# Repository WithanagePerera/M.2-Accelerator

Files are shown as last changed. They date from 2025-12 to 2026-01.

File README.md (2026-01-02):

# Artix-7 M.2 Hardware Accelerator

A custom M.2 PCIe hardware accelerator based around an (Xilinx) Artix-7 XC7A100T-1FGG484C that I designed in Altium for my own embedded computer vision and DSP projects.

# Motivation

During the Fall 2025 semester, I was a Project Lead for the **Machine Intelligence Lab's** Software team, specifically Computer Vision. For our autonomous submersible (*sub9*), we had a huge stack of CV-algorithms that fed into each other, but I was frustrated with our real-time performance since we're heavily resource constrainted running on an embedded system.

Earlier that year, a friend (shoutout Zack Mendez, best Digital Design TA) showed me how he could write and deploy some video-filtering kernels onto an FPGA ([Zack's RTIPCV Project](https://github.com/zack-mendez/fpgators-rtipcv/tree/main)).

That got me thinking, our computer vision stack for the submersible has several basic pre-processing layers, so if I can move those to a hardware accelerator, I can free up more GPU/CPU resources for the more complex CNNs.

My hardware accelerator would need to be a small form factor with high bandwidth which was how I landed on M.2, which our computer (Jetson Nano) has on newer versions.

What really pushed me forward with this project was seeing an M.2 hardware accelerator built by Phil Salmony using an Artix-7 A35T, and it proved to me that something of this scale was possible.

A final motivation was having a chance to tinker with Altium more, especially with high speed designs. As an Electrical Engineer, I feel like PCB development is one of those quintessential skills that kind of defines us, and is especially useful as an Embedded/Hardware guy.

# Schematic Design (12/20/25 - 01/01/26)

Took a break from my [SystemVerilog I2C-IP project](https://github.com/WithanagePerera/I2C-Interface-IP) to work on this.

Spent this time for my component selection, then designing all of my circuits in Altium like the power distribution for all of my voltage rails, configuration of the FPGA banks, the MGTs for PCIe, DDR3L, QSPI and JTAG, etc.

I plan on taking a break from this to finish off my I2C project, but the next step is validation of my circuits and running some signal integrity checks to check my transmission line effects on the high speed signals, then finally PCB development.

<table align="center" border="0">
  <tr>
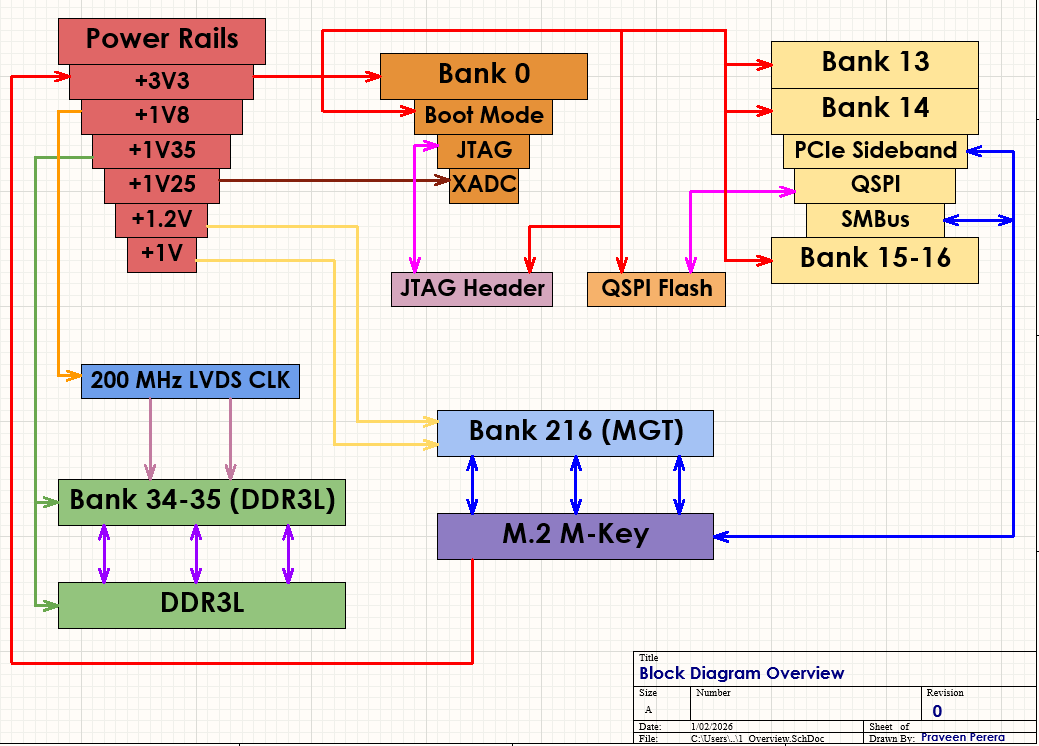
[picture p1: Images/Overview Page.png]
Block Diagram Overview
    <td></td>
  </tr>
  <tr>
    <td align="center" style="background:none;">Block Diagram Overview</td>
  </tr>
</table>

<br/>

<table align="center" border="0">
  <tr>
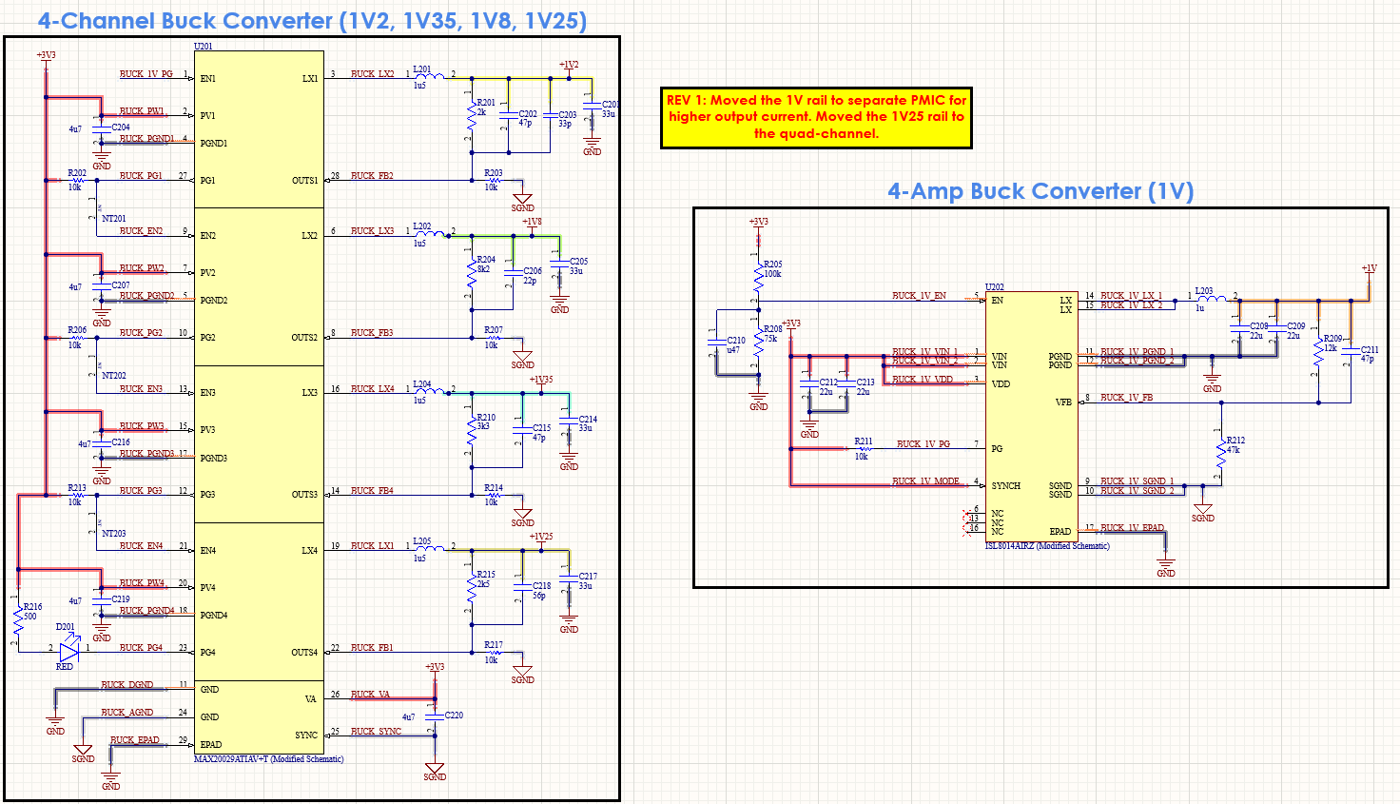
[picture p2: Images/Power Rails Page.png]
Power Rails
    <td width="50%"></td>
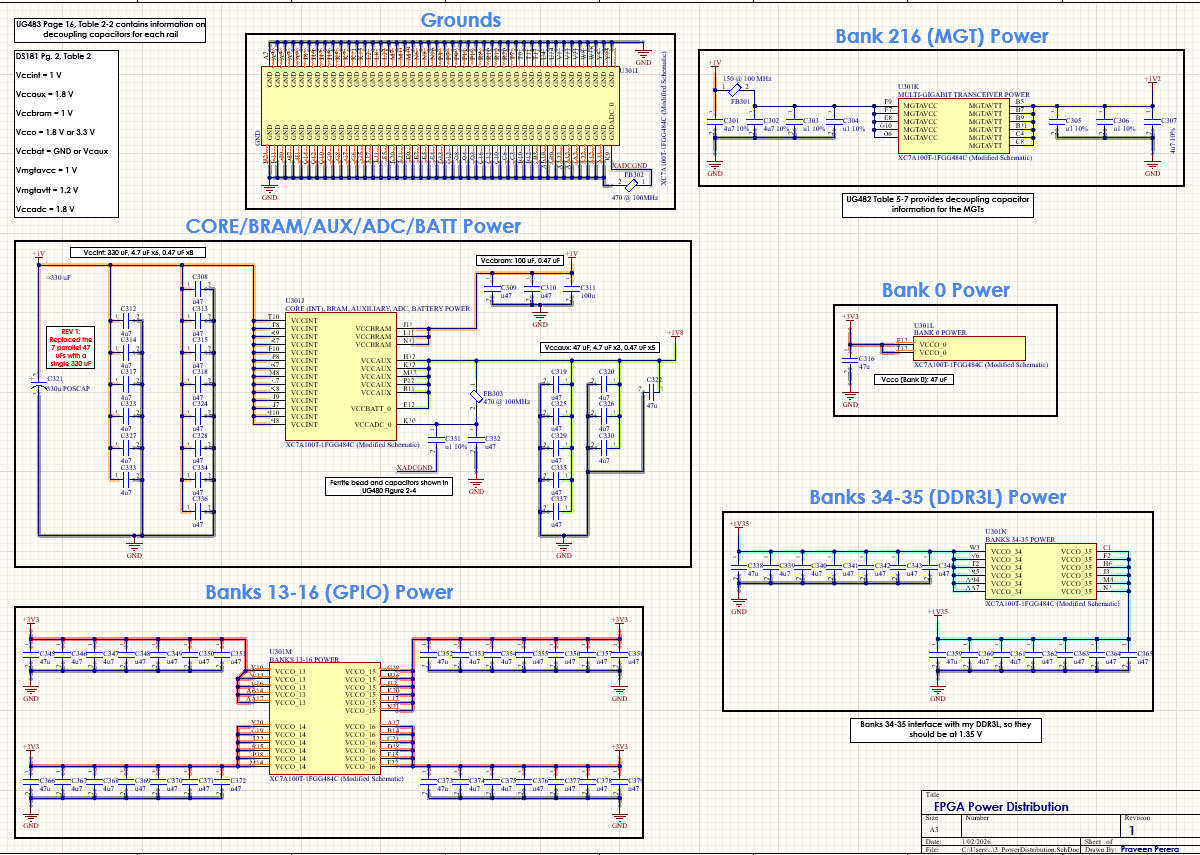
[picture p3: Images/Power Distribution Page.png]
Power Distribution
    <td width="50%"></td>
  </tr>
  <tr>
    <td align="center" style="background:none;">Power Distribution</td>
    <td align="center" style="background:none;">Power Rails</td>
  </tr>
</table>

<br/>

<table align="center" border="0">
  <tr>
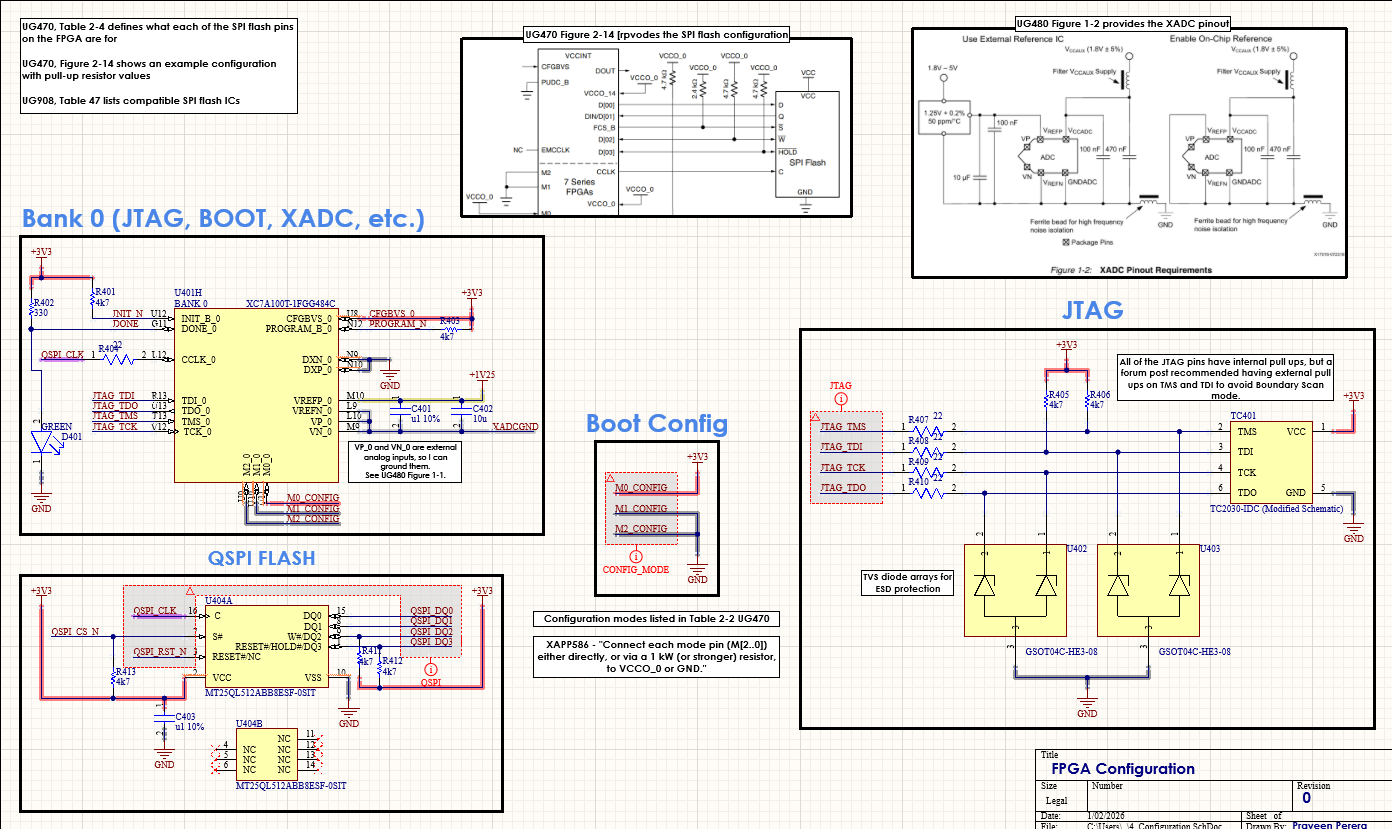
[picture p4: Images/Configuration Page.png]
FPGA Configuration
    <td width="50%"></td>
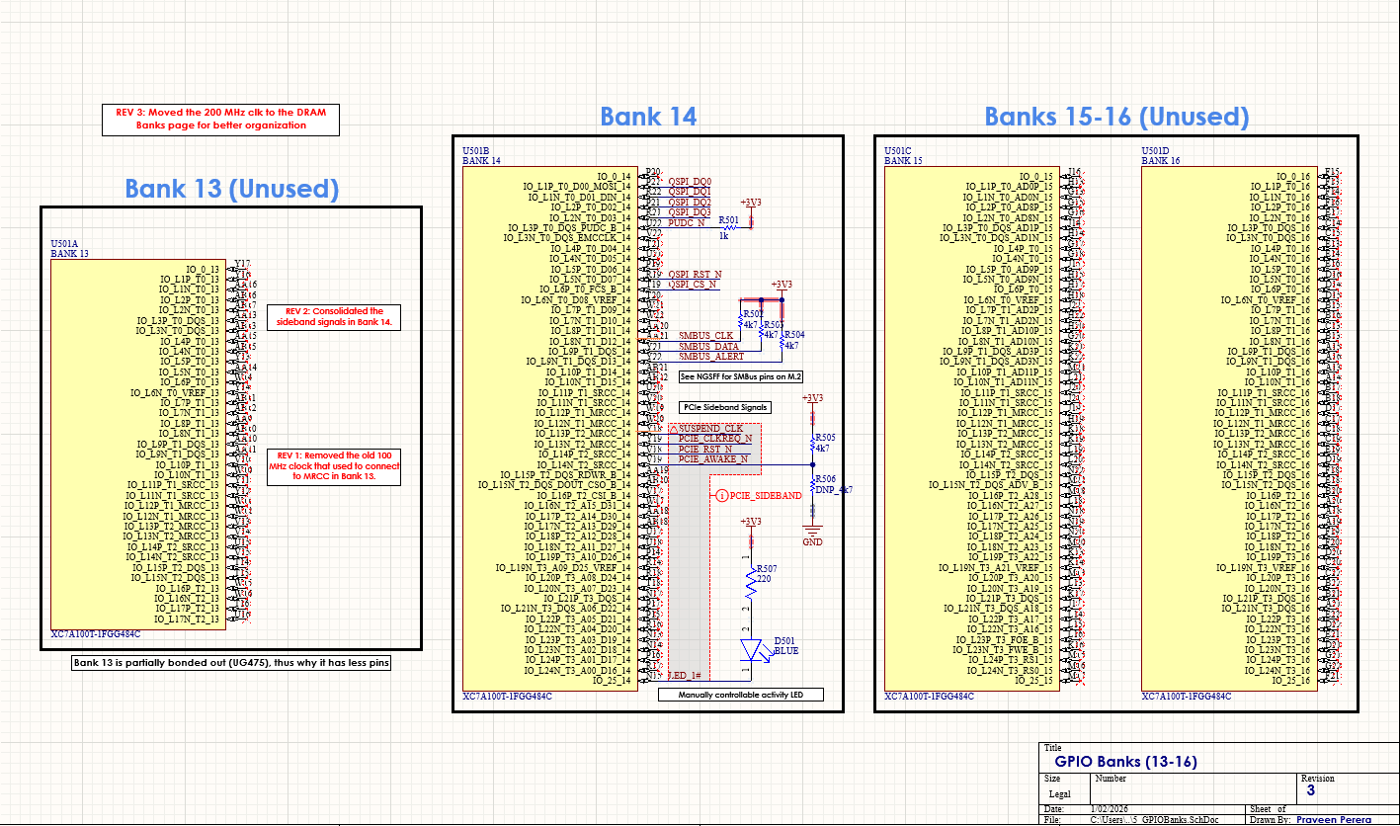
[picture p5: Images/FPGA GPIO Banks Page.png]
GPIO Banks
    <td width="50%"></td>
  </tr>
  <tr>
    <td align="center" style="background:none;">FPGA Configuration</td>
    <td align="center" style="background:none;">GPIO Banks</td>
  </tr>
</table>

<br/>

<table align="center" border="0">
  <tr>
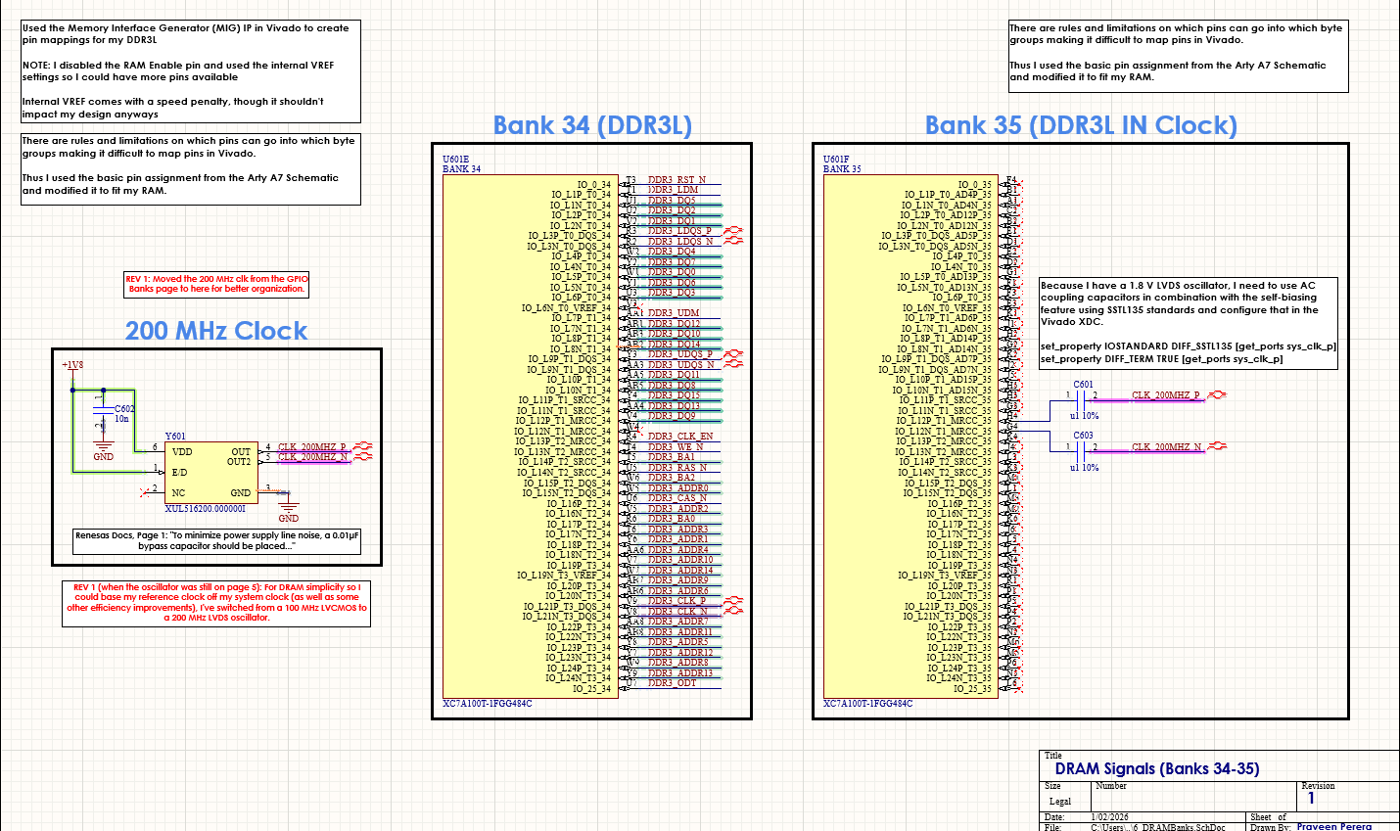
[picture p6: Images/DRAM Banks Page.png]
DRAM Banks
    <td width="50%"></td>
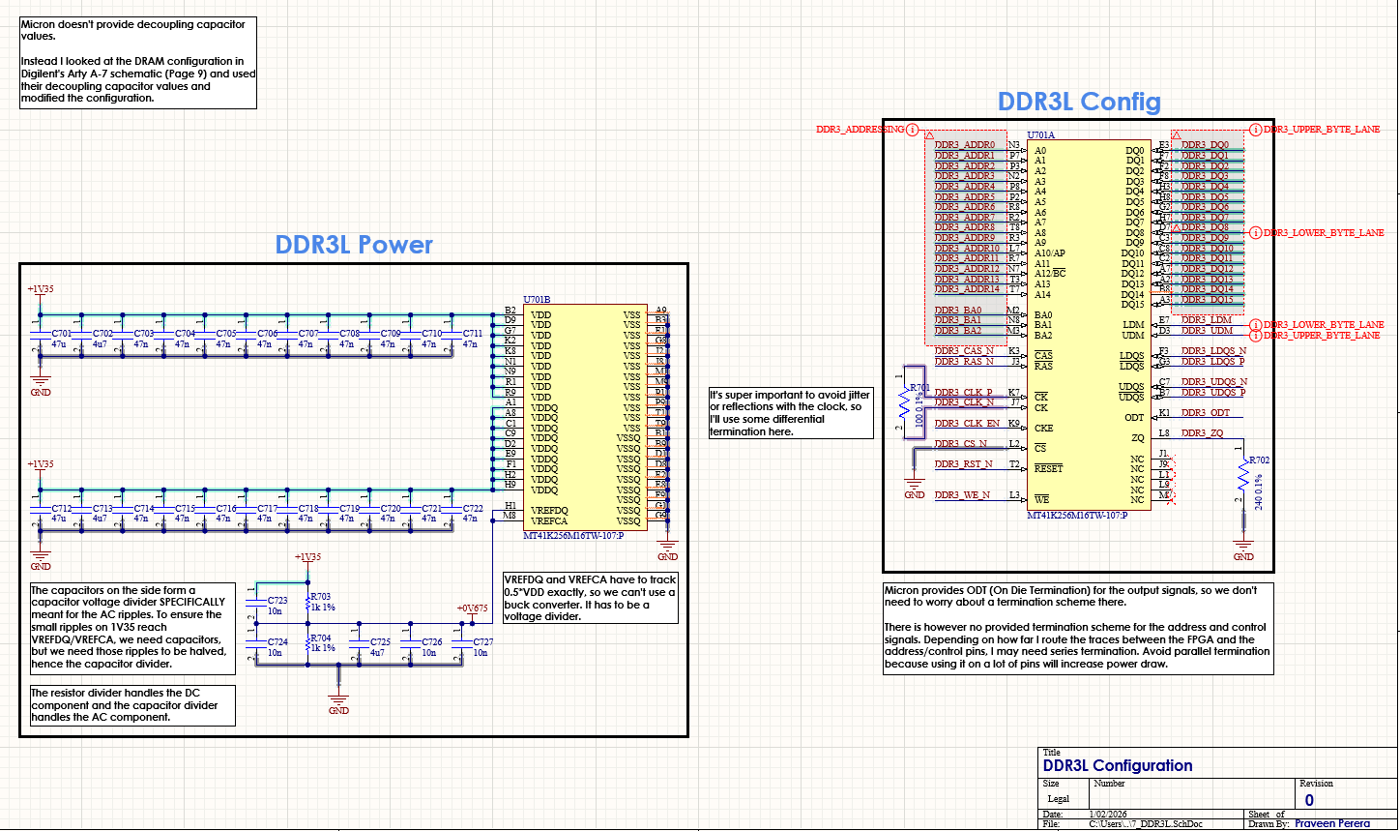
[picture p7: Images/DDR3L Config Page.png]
DDR3L Configuration
    <td width="50%"></td>
  </tr>
  <tr>
    <td align="center" style="background:none;">DRAM Banks</td>
    <td align="center" style="background:none;">DDR3L Configuration</td>
  </tr>
</table>

</br>

<table align="center" border="0">
  <tr>
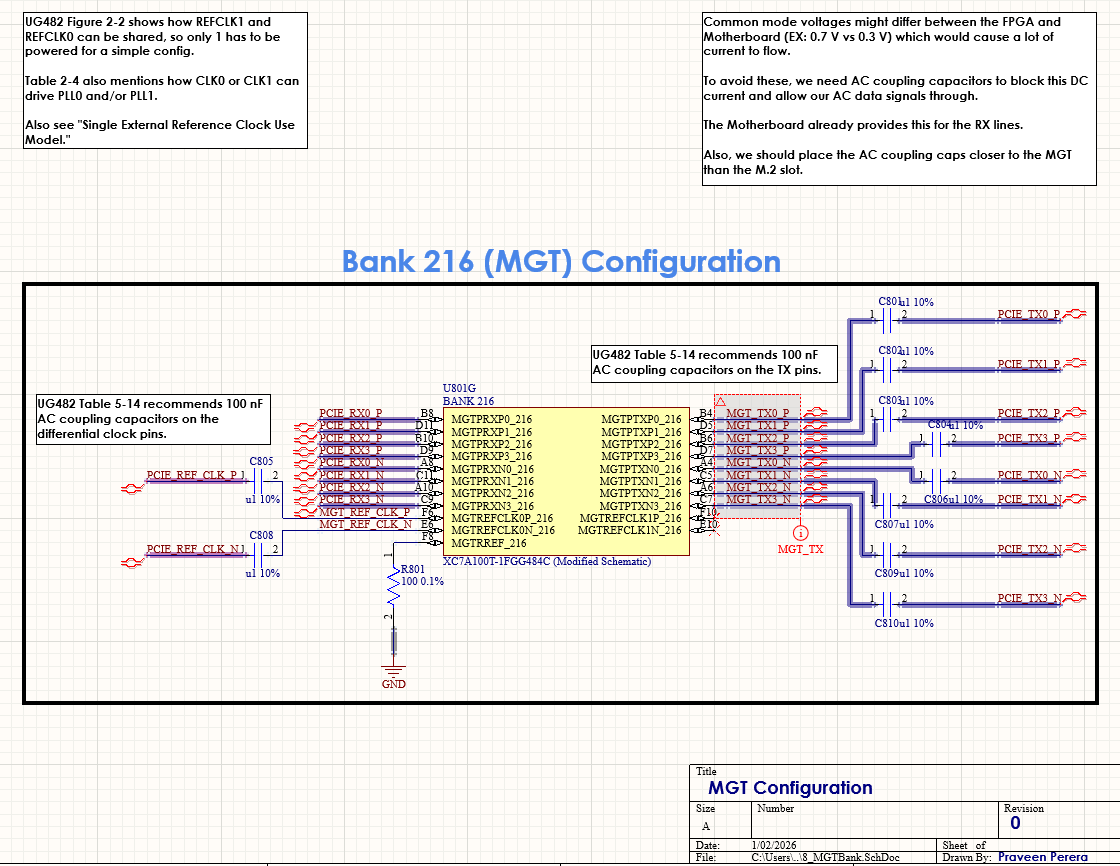
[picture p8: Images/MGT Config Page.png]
MGT Configuration
    <td width="50%"></td>
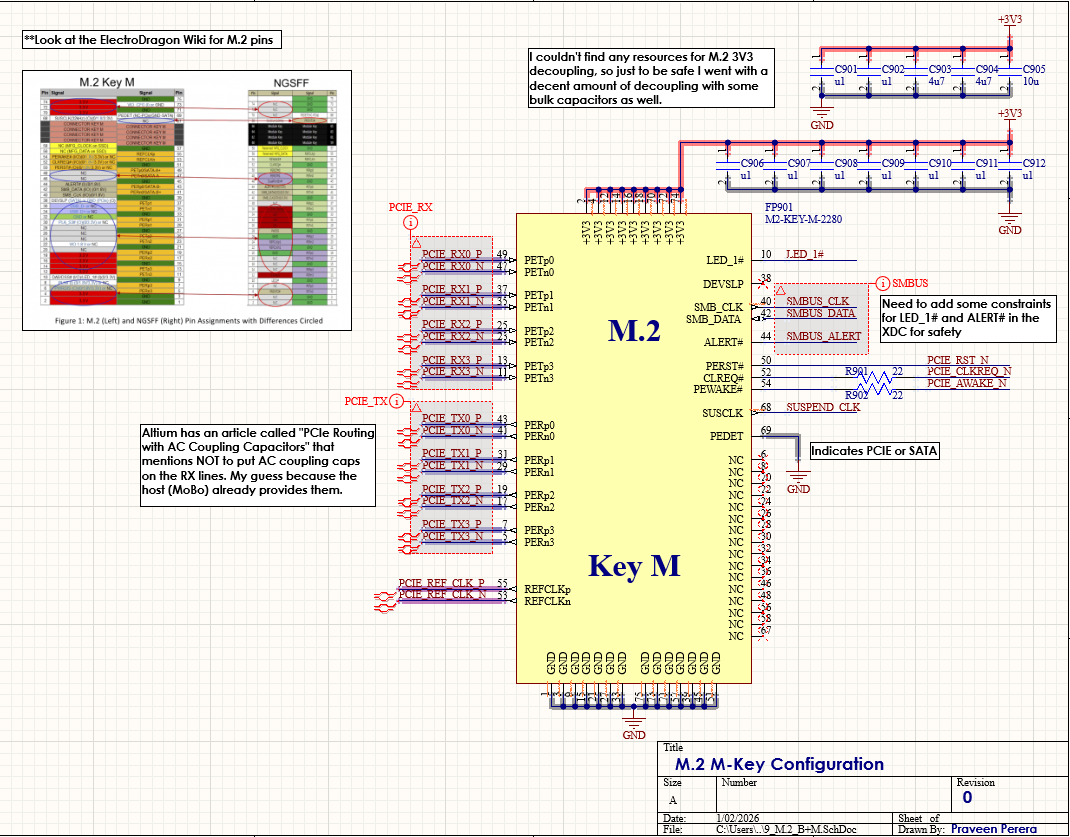
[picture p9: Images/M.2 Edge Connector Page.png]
M.2 M-Key Edge Connector
    <td width="50%"></td>
  </tr>
  <tr>
    <td align="center" style="background:none;">MGT Configuration</td>
    <td align="center" style="background:none;">M.2 M-Key Edge Connector</td>
  </tr>
</table>

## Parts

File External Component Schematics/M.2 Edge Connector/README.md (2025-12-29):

I derived this component from Phil's huge list of components (see the "Phil's Lab Altium Components" folder in the directory above). I separated the M.2 2280 M-key footprint and schematic from his list, and created a separate component for it here.

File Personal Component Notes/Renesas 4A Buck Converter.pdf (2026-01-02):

ISL8014A
https://www.renesas.com/en/document/dst/isl8014a-datasheet

Basics:
- SMPS -> More efficient than if I went with a LVPS which matters since the 1 V rail draws a large amount of current
- Up to 4 A continuous output
- Less than 0.4 V dropout at 4 A current draw
- 2.8 V to 5.5 V input
- Fast transient response
- Discontinuous operation at light load provides higher efficiency by reducing switching losses
- Forced continuous operation at light load reduces noise and RF interference
- Power good signal for when output is in regulation

Pin Descriptions:
Page 2
- VIN (Pins 1 and 2 to split the current between pins for lower resistance)
- Input supply. Use a 10 uF ceramic cap to ground.
- VDD
- Input supply for the analog switching circuitry in the IC, tied to VIN. Probably should add some isolation to ensure none of the switching noise gets on VIN.
■ I can create an RC lowpass filter using 22 ohms and 1 uF that has a cutoff of 7 kHz.
- EN
- Active high enable.
- It’s recommended that EN should be kept below 0.4 V until VIN reaches 2.5 V.
- PG
- Power good signal. It’s delayed by 1 ms after output voltage has stabilized.
- Needs a pull-up resistor to VIN. Used a 100k in the example application.
- SYNCH
- Mode selection pin
- HIGH (Connect to VDD, must be higher than 2.5 V): PWM mode, more efficient at high load
- LOW (Connect to GND, must be less than 0.4 V): PFM mode, more efficient at light load
- Or connect to external function generator.

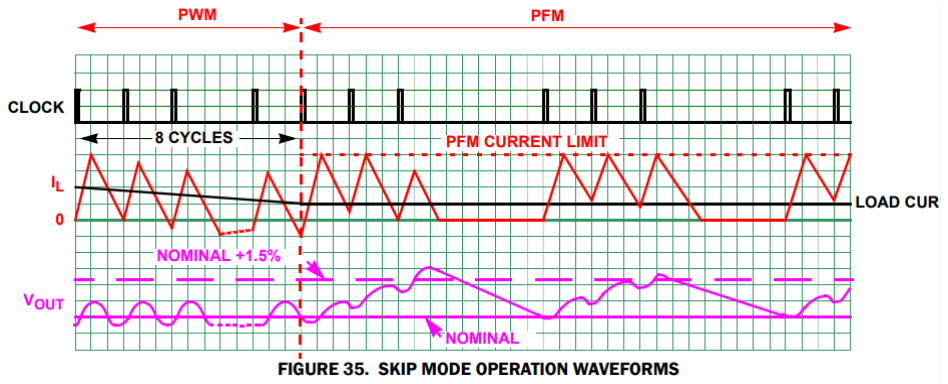
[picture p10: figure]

- LX (2 of them to handle high current, so tie their outputs together)
- Switching node output, connect to a series inductor.
- PGND
- Power ground
- SGND
- Signal ground
- VFB
- Output feedback. Connect to the output of the inductor at LX through a resistor divider for adjustable output.
- For 0.8 V output, connect to the output of the inductor with no resistor divider.
- Exposed Pad
- Must be connected to SGND pin.
- Place as many thermal vias as possible under this pad for optimal thermals.

Example Implementation
Page 3

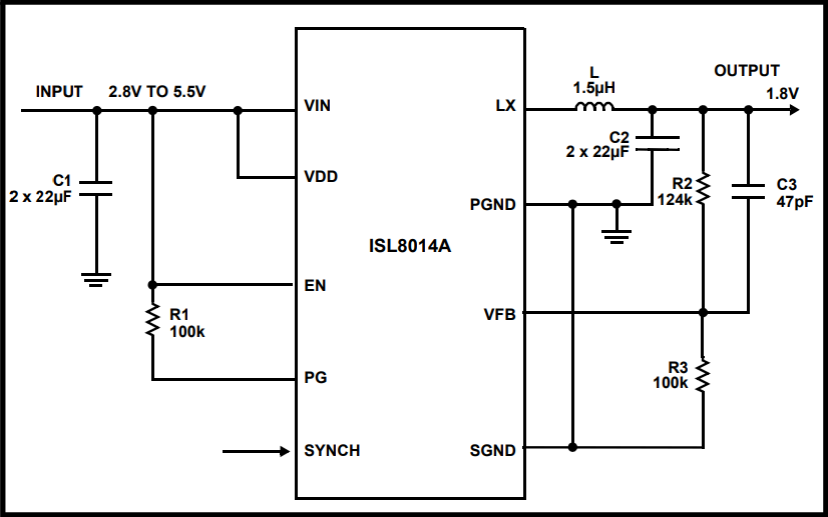
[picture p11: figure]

Typical Operating Performance
Page 6
- Based on Figure 1, PWM mode with 3.3 V input at 2 A and 1.2 V output is about 85% efficiency. At 1 V, that’s probably even lower because of the lower duty cycle.

Enable Signal Ramp Up:
Page 13

It’s recommended that the EN voltage be less than 0.4 V until VIN reaches 2.5 V.
The datasheet recommends using a voltage divider so that EN tracks VIN, but at a lower rate:

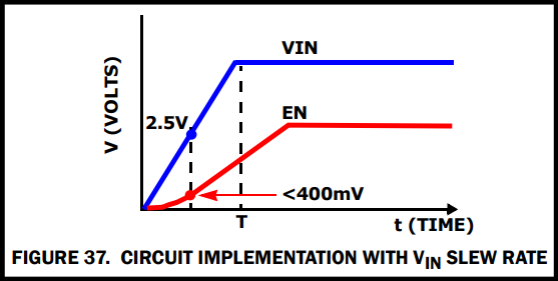
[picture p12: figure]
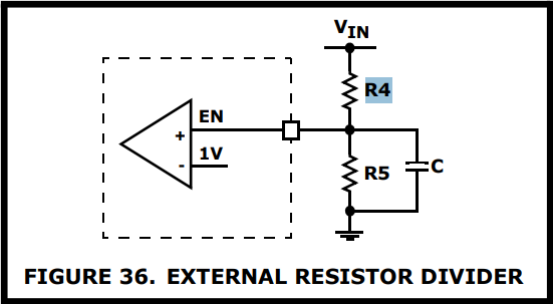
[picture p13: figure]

The datasheet provides an equation for calculating R4 based on R5 and VIN.

We need to select the ratio such that EN is 1.4 V (minimum to enable logic high) when VIN is equal to or greater than 2.5 V (for me, I’ll probably make that 2.9 V or 3 V).

Set R5 between 10k and 100k.

R4 = | | , I’ll go with R4 = 100k and R5 = 75k
| R5 * (Vin − 1.4 V) 1.4 V

Then we can select the capacitance such that the time constant is at least twice the rise time because that’ll allow the delay to EN to be high enough such that EN is still less than 0.4 V by the time VIN reaches 2.5 V (2.9 or 3 V for me).

T = rise time of VIN, I couldn’t find any values for this for M.2 M-key, so I’ll just shoot in the dark with 5 ms, but I’ll double that to 10 ms for safety
C >= | -> | = 4.7 * 10
2T | -7
R4 || R5

2 * 0.01 s
100k || 75k

Output Inductor and Capacitor Selection
Page 14

For higher output voltages (like 3.3 V), a higher inductance can be used to reduce current and voltage ripple on the output.

It’s recommended that inductor ripple current is 30% of the maximum output current for best performance.

Ripple Current (ΔI) =

VO * (1 −

VO
Vin

)
L * fs
- VO = output voltage
- VIN = input voltage
- fs = switching frequency of the PMIC

From my estimates using the Xilinx Power Estimator, my peak current on the 1 V rail is about 2.3 A. 30% of that would be 0.69 A.

0.69 A = | , solving we get L = 1.01 uH

1.004 V * (1 −

1.004 V
3.3 V

)
L * 1 MHz

The equation above can be rearranged to help me find the inductance to use, BUT Renesas also recommends the inductor have a saturation current over 7 A since the regulator can spike to 6 A under heavy load.

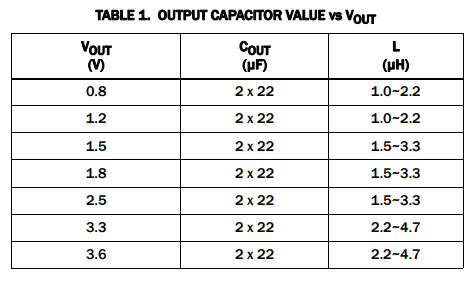
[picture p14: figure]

Additional output capacitances should be added when high load transients or low output ripple is required. -> I already added the decoupling caps that Xilinx recommended on the FPGA side for the 1 V rail, so I’ll just add a 4.7 uF here for some bulk.

Output Voltage Resistor Divide
Page 14

Feedback resistor is typically between 10k and 100k

R3 =

R2 * 0.8 V
Vout − 0.8 V

If you want the output to be 0.8 V, then you don’t need R3 and R2

is shorted.

For my implementation, I’ll go with R2 = 12k and R3 = 47k which yields about 1.004 V on the output. I want resistors on the lower end so I have a low impedance network which is less susceptible to interference.

For better performance, add 47 pF in parallel with R2 (100k).
- This 47 pF cap is what’s called a “feedforward capacitor” which improves transient response. Basically if the FPGA load increases suddenly, output voltage will dip. The 47 pF cap couples this change to the feedback pin on the PMIC, and it bypasses the resistor network to tell the PMIC to immediately boost output.
- In terms of control theory, the 47 pF cap adds a zero and pole to the open loop transfer function, which when placed properly will provide a phase boost.

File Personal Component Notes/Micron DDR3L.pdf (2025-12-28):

MT41K256M16TW-107:P

https://mm.digikey.com/Volume0/opasdata/d220001/medias/docus/6128/MT41K1G4_MT41K512M8_MT41K256M16_RevR_Sep2018.pdf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 AAAADrbLlhuIhfoUkRWjDnrL4PqzKPWi (https://mm.digikey.com/Volume0/opasdata/d220001/medias/docus/6128/MT41K1G4_MT41K512M8_MT41K256M16_RevR_Sep2018.pdf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..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)

I’ve chosen a 256x16 configuration. A[14:0] are used for row addresses, A[9:0] are for column addresses, and BA[2:0] are for bank selection.
- 2

15 = 32768
- 2

10 = 1024
- 2

3 = 8
- 32768 * 1024 = 33,554,432
- That means we have 33,554,432 UNIQUE addresses.
- Each address contains 1 word, which in our case is 16 bits.
- Thus each of our 8 banks hold 33,554,432 * 16 = 536,870,912 bits
- 536,870,912 * 8 = 4,294,967,296 bits = 4 Gigabits = 512 Megabytes

An FBD (Figure 5) is provided on Page 16 for the 256x16 version.

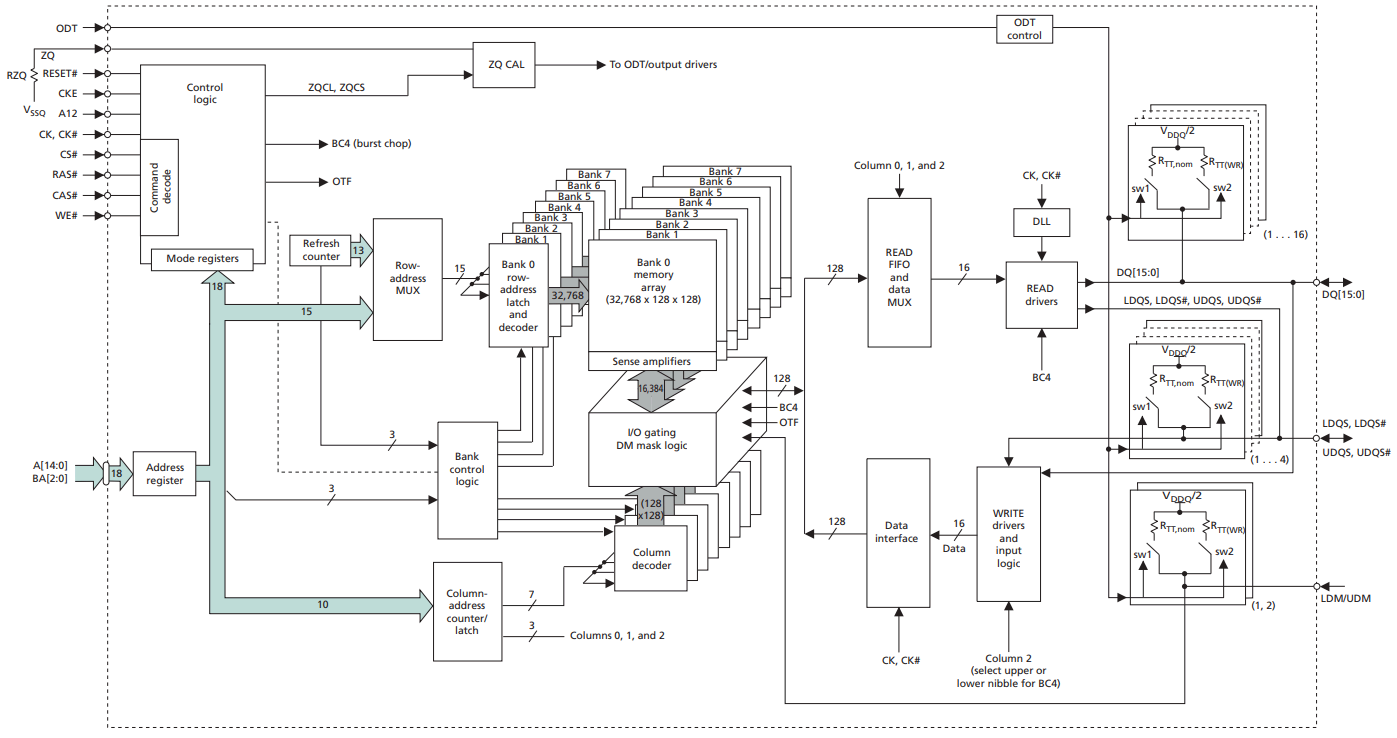
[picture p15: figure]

BGA arrangement is provided on Page 18 for the 256x16.

Pin Descriptions
Page 21
- A[14:0]: Address inputs.
- Provides the row address for ACTIVATE commands.
■ Because of the way DRAM works, it’s “destructive” by nature. Memory cells contain a capacitor and transistor.
■ Reading data from memory cells causes the capacitor to lose its charge because that charge is drained onto the bitline.
■ Sense amplifiers can see the data/charge that’s drained onto a bitline, convert that into a logic value (1/0), and write that back to the original memory cell to avoid destruction of data.
■ The ACTIVATE command basically opens a specific row in a specific memory bank, and does what I mentioned above with transferring that data into sense amplifiers.
- During READ/WRITE commands, A[9:0] provide the column address.
■ When not in ACTIVATE mode, some of the address pins are used for another purpose like A10 and A12:
- A10 is used as a PRECHARGE signal.
- If high, the row will be closed when the READ/WRITE operation is finished.
- If low, the row will stay open for another command which is more efficient than rerunning ACTIVATE.
- A12 is used as a “Burst Chop/BC” signal. This controls how much data comes out.
- If high, you get 8 bytes of data from a row.
- If low, that’s chopped and you get 4 which is useful if you want to save time and don’t need 8 bytes.
○
- The PRECHARGE command is used to close a row manually.
■ It’s done after a READ/WRITE operations or when we’re switching between rows in a bank.
■ A10 is used as a bank selector.
- If high, precharge is applied to all banks.
- If low, precharge is only applied to the bank selected by the Bank Address (BA[2:0]) pins.
- BA[2:0]: Bank address inputs.
- Recall from the FBD above that there’s 8 banks that can be selected.
- BA[2:0] define which bank an ACTIVATE, READ/WRITE, or PRECHARGE command is applied to.

- During LOAD MODE, BA[2:0] define which mode register (MR0, MR1, MR2, or MR3) is loaded. You can see the mode registers in the FBD above. They’re on the bottom of the “Control logic” block.
■ Mode registers control functionality like ODT (on die termination), refresh settings, burst length, write leveling, etc.
- CK/CK#: Differential pair of clock inputs.
- Differential pairs help with combatting EMI.
- All control/address signals are sampled when CK is on its positive edge and CK# is on its negative edge.
- CKE: Clock enable, active high.
- When high it enables, and when low it disables, internal circuitry and clocks.
- CS#: Chip select, active low.
- LDM: Input data mask.
- Lower byte, input mask signal for write data.
■ Because I chose 256x16 RAM, our word size is 16 bits.
■ Sometimes computers only need to modify 8 bits of data from RAM instead of 16 bits. ■ The lower byte mask allows us to leave the lower 8 bits unchanged during a WRITE.
- When LDM is high, the lower byte is masked.
- When LDM is low, the lower byte is modifiable during a WRITE.
- UDM: Upper byte input data mask.
- Same principle as LDM.
- ODT: On-die termination, active high.
- ODT are resistors on the die that can be activated to help with impedance matching and reduce reflections.
- When high, termination resistance is enabled.
■ It applies to DQ[15:0], LDQS, LDQS#, UDQS, LDM, and UDM.
- These signals were chosen because they operate at a higher speed and are more prone to transmission line effects.
- RAS#, CAS#, WE#: Define the command being entered. You can think of the 3 bits together as being opcodes.
- RAS = Row Access Strobe, when low the DRAM will latch the row address pins (lock them) and send them to row decoders to trigger the appropriate sense amplifiers.
- CAS = Column Access Strobe, when low the DRAM will latch the address pins and send them to column decoders to pick a specific piece of data from an already open row.
- WE = Write Enable, determines direction of data (in/out).
- RESET#: Active low asynchronous reset.
- DQ[7:0]: Data output AND input (if we want to read or write data to RAM).
- The lower byte.

- DQ[15:8]: Upper byte for data input/output.
- LDQS/LDQS#: Basically a differential pair for a local clock for the lower bits (DQ[7:0]).
- There’s a global clock that originates from the CPU/FPGA, and that’s used for determining when to sample the address lines and when to check for commands.
- This global clock has to travel to every DRAM chip, so it takes a long and complex path, but at high speed, that makes transmission line effects more important so it can’t be used to precisely time data bits on DQ[15:0].
- The memory controller also has local data clocks called “Local Strobe” (DQS) that travel simpler paths alongside the data bits, so they experience the same delay. Thus they are better synchronized.
- During memory training for boot up, the memory controller will send test patterns on the DQS to see which timing is best synchronized.
- There’s also some relevant information about reads and writes relating to this data clock:
- Just a notices, READs and WRITEs are from the perspective of the CPU/FPGA, so a WRITE is the CPU/FPGA sending data to DRAM.
- Center-Aligned WRITES
■ When the CPU/FPGA memory controller is writing data to RAM, it will send the data bits, then wait 90* (quarter cycle) before sending the data clock strobe (DQS). It controls both data and DQS.
- This is similar to what I do with SDA and SCL in I2C to ensure SDA is sampled only when it has stabilized.
■ Thus the DQS edge arrives in the middle of the data window, thus that data line is stabilized when DRAM samples it.
- Edge-Aligned READS
■ DRAM is simpler for costs, so it doesn’t add a shift to DQS like the memory controller does.
■ Instead DRAM will send DQ and DQS at the same time so that their edges are aligned. DRAM controls both data and DQS for reads.
■ From there, the memory controller on the CPU/FPGA (which is smarter) will shift the DQS to sample the data at the correct time.
- It gets more complex when you consider Double Data Rate where we sample on rising and falling edges, but the concept is the same. We still have a 90* delay before sampling after a rising edge, and a falling edge.
○
- UDQS/UDQS#: Differential clock for the upper byte (DQ[15:8]).
- We have this separation for local clocks between upper and lower bytes because those bytes are pretty independent. We can read/write to just an upper byte or lower byte if we want.

- VDD: Input power (1.35 V)
- VDDQ: DQ power supply used for output signals. When signals are going out, they feed directly from VDDQ and draw more power.
- VREFCA: Reference voltage for control, command, and address. Must be maintained at all times.
- VREFDQ: Reference voltage for data, must be maintained at all times.
- VSS: Ground.
- VSSQ: Isolated from normal VSS for better noise immunity.
- ZQ: Calibration to ensure the strength of the signals of the signals leaving DRAM is right and that ODT resistance is right. Use a HIGH PRECISION 240 ohm resistor.

Electrical Specifications
Page 49

IMPORTANT: Micron hasn’t provided any decoupling capacitor specifications. Probably because single DRAM chips are expected to go onto a larger DIMM.

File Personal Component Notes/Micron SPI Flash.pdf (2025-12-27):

MT25QL512ABB8ESF-0SIT
https://mm.digikey.com/Volume0/opasdata/d220001/medias/docus/7161/MT25QL512ABB8ESF-0SIT.pdf

As far as PCB design goes, not everything in the datasheet matters to us like extended addressing, security registers, programming, etc. because that’ll be handled by the bitstream generated in Vivado.

Basic Info:
- 2.7-3.6 V operating range
- 512 MegaBit density -> 64 MB per chip

Signal Assignments:
Our package code is SF (...8ESF-0SIT), so we’ll use the pinout on Page 13.
Notice that 7 pins are marked as DNU (Do Not Use). That explains why the IC has 16 pins, but the schematic in Altium only uses 9 pins.

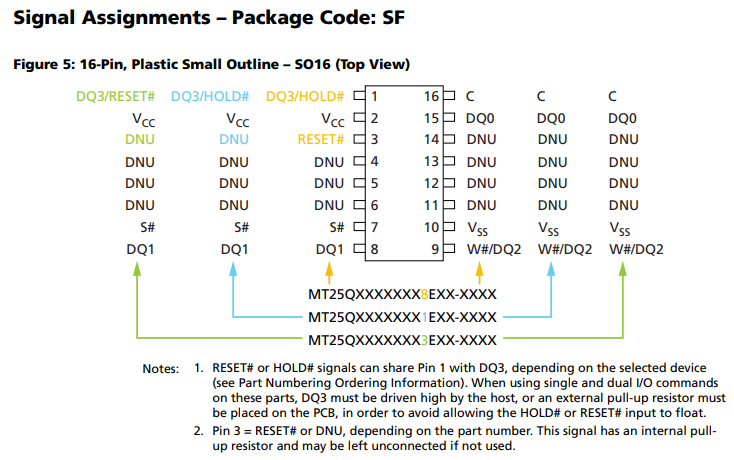
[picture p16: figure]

Signal Descriptions:
Page 14
- S# (Input): Chip select, active low.
- Running it high puts the device in standby mode and tri-states all output pins and input pins (besides RESET) are ignored.
- Driving it low enables the device (active mode).
- After power up, there has to be a falling edge on S# before any commands are sent. That means you can’t just keep S# low during activation as well as when you want to use the flash.
- C (Input): Clock. This device is CPOL = 0 (polarity = 0) meaning clock idles low.
- Therefore the device looks at inputs on the rising edge of the clock, and data is outputted on the falling edge.
- RESET# (Input): Active low reset.
- When driven low, device is reset and outputs are tri-stated. Data may be lost if a reset happens while the FLASH is doing some operation (WRITE, PROGRAM, ERASE, etc).
- HOLD# (Input): Pauses communication.
- For my IC, HOLD# and DQ3 share the same pin.
- It’s only used in regular SPI mode, not in QSPI. In QSPI, HOLD# functionality is disabled so that the pin can be used as a 3rd data line.
- W# (Input): Freezes the status register from getting modified. The status register holds flags which gives information about the operations that are happening, and firmware you write can read or modify the status register.
- W# is write protection to prevent firmware from modifying the status register.
- It shares a pin with DQ2.
- In QSPI mode, the pin is used for input/output as DQ2.
- **DQ[3:0] (Input/Output): Bidirectional DQ signals for address, command, and data.
- In regular SPI mode, DQ0 and DQ1 are for MISO and MOSI. DQ2 and DQ3 are used for HOLD# and RESET as mentioned earlier.
- VCC (Supply): Supply voltage.
- VSS (Supply): Ground connection.

Supported Clock Frequencies (STR Mode): Page 28, Table 10 (IT Parts)
For QAD I/O Fast Read (MHz):
- 39
- 48
- 58
- 69
- 78

- 86
- 97
- 106
- 115
- 125
- 133

Power Up/Power Down:
Page 80
Use a decoupling capacitor of 100 nF.

Important: During power up/power down, the device MUST NOT be selected (S# != 0). S# must follow the voltage applied on VCC until VCC reaches the correct values. Only after VCC reaches 3.3 V (in my case) can S# be toggled to 0 to enable the device.
- That’s why S# has a pull up resistor. The FCS_B pin on the FPGA is likely an open drain connection that can go high-Z during startup to avoid enabling the FLASH and having it read garbage addresses/commands from the database (which are also open drain and probably floating at this point).

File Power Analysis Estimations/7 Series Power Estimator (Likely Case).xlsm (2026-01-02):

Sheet: Summary
 |  |  | Xilinx Power Estimator (XPE) - 2019.1.2 |  |  |  |  |  |  |  |  |  |  |  |  |  |  |  |  |  |  |  |  |  |  |  |  | 1 |  | Pkgs | 1 | CLKROW | CLKCOL | LUT | FF | BRAM | MMCM | PLL | DSP | GT | PCIE |  | 3.3 Pins | Pins | Banks | ThetaJA | ThetaJB
 |  | Spartan®-7, Artix®-7, Kintex®-7, Virtex®-7, Zynq®-7000 |  |  |  |  |  |  |  |  |  |  | Release: 14-Aug-2019 |  |  |  |  |  |  |  |  |  |  |  |  |  |  |  |  | FTG256 | 7 | 4 | 54 | 63400 | 126800 | 135 | 6 | 6 | 240 | 0 | 1 | 0 | 285 | 285 | 17 | 15.8 | 6.8
 |  |  |  |  |  |  |  |  |  |  |  |  |  |  |  |  |  |  |  |  |  |  |  |  |  |  |  |  |  | CSG324 | 1 | 1 |  | 38016 |  |  |  |  |  | 0
 |  |  |  |  |  |  |  |  |  |  |  |  |  |  |  |  |  |  |  |  |  |  |  |  |  |  |  |  |  | FGG484 |  | 1
Project |  |  |  |  |  |  |  |  |  |  |  |  |  |  |  |  |  |  |  |  |  |  |  |  |  |  |  |  |  | FGG676 |  |  |  |  |  |  |  |  |  | 4
Settings |  |  |  |  | Summary
Device |  |  |  |  | Total On-Chip Power |  |  | 2.731 W |  |  | 21.51576541% | Transceiver…… |  | 0.587W
Family | Artix-7 |  |  |  |  |  |  |  |  |  | 11.18250154% | I/O……………… |  | 0.305W
Device | XC7A100T |  |  |  | Junction Temperature |  |  | 35.5 °C |  |  | 63.44882036% | Core Dynamic.. |  | 1.733W
Package | FGG484 |  |  |  | Thermal Margin |  |  | 49.5°C | 12.7W |  | 3.852912684% | Device Static….. |  | 0.105W |  |  |  |  |  |  |  |  |  |  |  |  |  | 10 | 2.16 | 0.09
Speed Grade | -1 |  |  |  | Effective ΘJA |  |  | 3.8 °C/W |  | Power supplied to off-chip devices… |  |  |  | 0.000W |  |  |  |  |  |  |  |  |  |  |  |  |  | 25 | 2.17 | 0.09
Temp Grade | Commercial |  |  |  |  |  |  |  |  |  |  |  |  |  |  |  |  |  |  |  |  |  |  |  |  |  |  | 40 | 2.19 | 0.11
Process | Typical |  |  |  | On-Chip Power |  |  |  |  |  | Power Supply |  |  |  |  |  |  |  |  |  |  |  |  |  |  |  |  | 55 | 2.22 | 0.14
Voltage ID Used | No |  |  |  | Resource |  |  | Power |  |  | Source |  | Voltage | Total (A) | Static | Active |  |  |  |  |  |  |  |  |  |  |  | 70 | 2.27 | 0.20 |  |  |  |  |  | static | 0
Characterization | Production |  |  |  |  |  | (Jump to sheet) | (W) | (%) |  | VCCINT |  | 1.000 | 1.437 | 0.023 | 1.413 |  |  |  |  |  |  |  |  |  |  |  | 85 | 2.36 | 0.29 |  |  |  |  |  |  | 1
 |  |  |  |  | Core Dynamic |  |  | 0.403 | 14.74445527 |  | VCCBRAM |  | 1.000 | 0.015 | 0.002 | 0.014 |  |  |  |  |  |  |  |  |  |  |  | 100 | 2.51 | 0.43 |  |  |  |  |  |  | 1
Environment |  |  |  |  |  |  |  | 0.489 | 17.91161348 |  | VCCAUX |  | 1.800 | 0.298 | 0.019 | 0.279 |  |  |  |  |  |  |  |  |  |  |  |  |  |  |  |  |  |  |  |  | 1
Junction Temperature |  |  | 35.5 °C |  |  |  |  | 0.240 | 8.804361075 |  | VCCAUX_IO |  | 2.000 | 0.000 | 0.000 | 0.000 |  |  |  |  |  |  |  |  |  |  |  | 0.95 | 2.10 |  |  |  |  |  |  |  | 1
Ambient Temp | 25.0 °C |  |  |  |  |  |  | 0.140 | 5.145318284 |  | VCCO 3.3V |  | 3.300 | 0.000 | 0.000 | 0.000 |  |  |  |  |  |  |  |  |  |  |  | 0.975 | 2.14 |  |  |  |  |  |  | 0 | 1
Effective ΘJA |  |  | 3.8 °C/W |  |  |  |  | 0.080 | 2.942863857 |  | VCCO 2.5V |  | 2.500 | 0.000 | 0.000 | 0.000 |  |  |  |  |  |  |  |  |  |  |  | 1 | 2.18 |  |  |  |  |  |  | 0 | 1
Airflow | 250 LFM |  |  |  |  |  |  | 0.223 | 8.18189472 |  | VCCO 1.8V |  | 1.800 | 0.000 | 0.000 | 0.000 |  |  |  |  |  |  |  |  |  |  |  | 1.025 | 2.22 |  |  |  |  |  |  | 0 | 1
Heat Sink | None |  |  |  |  |  |  | 0.098 | 3.594204064 |  | VCCO 1.5V |  | 1.500 | 0.000 | 0.000 | 0.000 |  |  |  |  |  |  |  |  |  |  |  | 1.05 | 2.27 |  |  |  |  |  |  | 0 | 1
ΘSA | 0.0 °C/W |  |  |  |  |  |  | 0.058 | 2.124109607 |  | VCCO 1.35V |  | 1.350 | 0.123 | 0.004 | 0.119 |  |  |  |  |  |  |  |  |  |  |  |  |  |  |  |  |  |  |  | 0.004 | 1
Board Selection | Medium (10"x10") |  |  |  | I/O |  |  | 0.305 | 11.18250154 |  | VCCO 1.2V |  | 1.200 | 0.000 | 0.000 | 0.000 |  |  |  |  |  |  |  |  |  |  |  |  |  |  |  |  |  |  |  | 0 | 1
# of Board Layers | 12 to 15 |  |  |  | Transceiver |  |  | 0.587 | 21.51576541 |  | MGTVCCAUX |  | 1.800 | 0.000 | 0.000 | 0.000 |  |  |  |  |  |  |  |  |  |  |  |  |  |  |  |  |  |  |  |  | 1
ΘJB | 2.6 °C/W |  |  |  |  |  |  | 0.000 | 0 |  | MGTAVCC |  | 1.000 | 0.254 | 0.002 | 0.252 |  |  |  |  |  |  |  |  |  |  |  |  |  |  |  |  |  |  |  |  | 1
Board Temperature | 25.0 °C |  |  |  |  |  |  | 0.000 | 0 |  | MGTAVTT |  | 1.200 | 0.238 | 0.003 | 0.235 |  |  |  |  |  |  |  |  |  |  |  | Temp | 50 | 85 | 100 |  |  |  |  |  | 1
 |  |  |  |  |  |  |  | 0.000 | 0 |  | - |  | 1.800 | 0.000 | 0.000 | 0.000 |  |  |  |  |  |  |  |  |  |  |  | Typical (1.0V) | 2.21 | 2.36 | 2.510693898 |  |  |  |  | 0 | 1
Implementation |  |  |  |  | Device Static | 0.105 |  | 0.105 | 3.852912684 |  | - |  | 1.075 | 0.000 | 0.000 | 0.000 |  |  |  |  |  |  |  |  |  |  |  | Maximum (1.05V) | 2.44 | 2.86 | 3.188937044 |  |  |  |  | 0 | 1
Optimization | Default |  |  | 1 |  |  |  |  |  |  | - |  | 1.075 | 0.000 | 0.000 | 0.000 |  |  |  |  |  |  |  |  |  |  |  |  |  |  |  |  |  |  |  | 0 | 1
 |  |  |  |  |  |  |  |  |  |  | - |  | 1.500 | 0.000 | 0.000 | 0.000 |  |  |  |  |  |  |  |  |  |  |  |  |  |  |  |  |  |  |  |  | 1
Messages |  |  |  |  |  |  |  |  |  |  | - |  | 1.800 | 0.000 | 0.000 | 0.000 |  |  |  |  |  |  |  |  |  |  |  |  |  |  |  |  |  |  |  |  | 1
 |  |  |  |  |  |  |  |  |  |  | - |  | 1.800 | 0.000 | 0.000 | 0.000 |  |  |  |  |  |  |  |  |  |  |  |  |  |  |  |  |  |  |  |  | 1
 |  |  |  |  |  |  |  |  |  |  | VCCADC |  | 1.800 | 0.020 | 0.020 | 0.000 |  |  |  |  |  |  |  |  |  |  |  |  |  |  |  |  |  |  |  | 0.02 | 1
XILINX Power Advantage (check for updates) (http://www.xilinx.com/products/technology/power/index.htm) |  |  |  | File Support Request (WebCase) (https://www.xilinx.com/support.html) |  |  |  |  |  |  | Xilinx Power Estimator User Guide (http://www.xilinx.com/cgi-bin/docs/rdoc?l=en;v=latest;d=ug440-xilinx-power-estimator.pdf)
© Copyright 1994-2019 Xilinx, Inc. All Rights Reserved |  |  |  | Introduction to XPE (video) (http://www.xilinx.com/training/vivado/using-the-xilinx-power-estimator.htm) |  |  |  | Whitepaper - 7 Steps for Worst Case Power Estimation (http://www.xilinx.com/support/documentation/white_papers/wp353.pdf)
Legend |  | User Entry |  |  | Calculated Value |  | Summary Value |  |  | User Override |  | Warning |  | Error
 |  |  |  |  |  |  |  |  |  |  |  |  |  |  |  |  |  |  | JEDEC | 12.1
 |  |  |  |  | Piccq | Iccauxq | Tj | Iccq |  |  |  |  |  |  |  |  |  |  | BoardType | 2 |  | Airflow | Opt | Leakage | 0.105 | 23.3296998 | Utilization
 |  |  |  | 0.001518669163 | 0 | 0.01883199455 | 35.39282284 | 0.02339326041 | Non-int Leakage | 0.0341 |  |  |  |  |  |  |  |  | BoardLyr | 2 |  | N/A | Default | CLOCK | 0.402605592 | 1.518669163
 |  |  | Temp | 35.39282284 | 0 | 0.0188253476 | 35.32054413 | 0.02332995407 | Scaled ICCQ_D | 0.0157 |  |  |  | Max Adj | Typ Adj |  |  |  | Airflow | 1 |  | 0 | Power Optimization | LOGIC | 0.4890866171 | 18.82532092
 |  |  | Initial | 35.2860151 | 0 | 0.01882532102 | 35.32025455 | 0.02332970082 | Non-aux Leakage | 0.0322 |  |  | MMF Factor | 1 | 0.9 |  |  |  | Heatsink | 3 |  | 250 | Powered Off | BRAM | 0.240408 | 0
 |  |  | Max | 125 | 0 | 0.01882532092 | 35.32025339 | 0.0233296998 | Scaled ICCAUXQ_D | 0.1086 |  |  | MMF Aux | 1 | 1.38 |  |  |  | Pkg size | 529 |  | 500 | Y44:Y45 | DSP | 0.1404957915 | 0
 |  |  |  |  | 0 | 0.01882532092 | 35.32025338 | 0.0233296998 | Iccint_c1 | 1.083667432e-05 |  |  | MMF Bram | 1 | 0.7 |  |  |  | Air | 315.0598614 |  | 750 |  | PLL | 0.08035654241 | 0
 |  |  |  |  | 0 | 0.01882532092 | 35.32025338 | 0.0233296998 | Iccint_c2 | 0.0034 |  |  | VID Factor | 1 |  |  |  |  | ThetaSA | 0.000 |  | X45:X48 |  | MMCM | 0.2234112083 | 0
 |  |  |  |  | 0 | 0.01882532092 | 35.32025338 | 0.0233296998 | Iccintq_d | 0.0165 |  |  | Bali Factor | 1 |  |  |  |  | ThetaCS | 0.100 |  |  |  | PHASER | 0.0981417508 | 0
 |  |  |  |  |  |  |  |  | Iccintq_des | 0.0174 |  |  | Vccint | 2.068090477e-06 | 1.083667432e-05 | 0.003371762837 | 0.3283375125 | 5.19520427 | ThetaJB | 6.800 |  |  |  | PCIE | 0.058 | 4
 |  |  |  |  |  |  |  |  | Iccaux_c1 | -1.578356583e-06 |  |  | Vccaux | 1.986522681e-07 | -1.578356583e-06 | 0.0006360548088 | -0.007539738889 | 12.87473391 | ThetaJA | 3.847 |  |  |  | IO | 0.3053444546 | 0
 |  |  |  |  |  |  |  |  | Iccaux_c2 | 0.0006 |  |  | Vccbram | 1.10180825e-07 | -1.360770486e-06 | -8.670494492e-06 | 0.01047253566 | 0.06813210322 | ThetaJX | 3.894 |  |  |  | GTP | 0.5875 | 0
 |  |  |  |  |  |  |  |  | Iccauxq_d | 0.0131 |  |  |  |  |  |  |  |  | eThetaJA | 3.847 |  |  |  |  | 0 | 2.012971074
 |  |  |  |  |  |  |  |  | Iccoq | 0.0040 |  |  |  |  |  |  |  |  | TJA-Top | 12.100 |  |  |  |  |  | 2.549180477
 |  |  |  |  |  |  |  |  | Iccbram_c1 | -1.360770486e-06 |  |  |  |  |  |  |  |  | TJ | 36.887 |  |  |  |  |  | 0
 |  |  |  |  |  |  |  |  | Iccbram_c2 | -8.670494492e-06 |  |  |  |  |  |  |  |  | eThetaJA | 4.353 |  |  |  |  |  | 0
 |  |  |  |  |  |  |  |  | Iccbramq | 0.0012 | 0.000936 | 1.223483401 |  |  |  |  |  |  | Power | 2.708 |  |  |  |  |  | 0
 |  |  |  |  |  |  |  |  | Process | 1.0000 |  |  |  |  |  |  |  |  | Power2 |  |  |  |  |  |  | 0
 |  |  |  |  |  |  |  |  | I-Grade | 0.3283 |  |  |  |  |  |  |  |  | Temp | 57.772 |  |  |  |  |  | 0
 |  |  |  |  |  |  |  |  | Q-Grade | 5.1952 |  |  |  |  |  |  |  |  | Temp | 36.791 |  |  |  |  |  | 0
 |  |  |  |  |  |  |  |  | I-Grade | -0.0075 |  |  |  |  |  |  |  |  | Temp | 57.35 |  |  |  |  |  | 20
 |  |  |  |  |  |  |  |  | Q-Grade | 12.8747
 |  |  |  |  |  |  |  |  | I-Grade | 0.0105 |  |  |  | PowerUp | Int | Aux | I/O | Aux_io | Bram | Avcc | Avtt | GTVccaux
 |  |  |  |  |  |  |  |  | Q-Grade | 0.0681 |  |  |  | Adder | 0.17 | 0.04 | 0.04 | 0 | 0.06 | 0.04 | 0.06 | 0.04
 |  |  |  |  |  |  |  |  | Vcc_c1 | 0.0885 |  |  |  | Min | 0 | 0 | 0 | 0 | 0 | 0 | 0 | 0
 |  |  |  |  |  |  |  |  | Vcc_c2 | 2.4249
 |  |  |  |  |  |  |  |  | VccScale | 0.9001
 |  |  |  |  |  |  |  |  | VccAuxScale | 1.38
 |  |  |  |  |  |  |  |  | VccBramScale | 0.7001
 |  |  |  |  |  |  |  |  | AVccScale | 1.0001
 |  |  |  |  |  |  |  |  | Max bram | 0.005953071524
 |  |  |  |  |  |  |  |  | Max PS | 0
 |  |  |  |  |  |  |  |  | Max Aux | 0.04721366955
 |  |  |  |  |  |  |  |  | Max Int | 0.1720755674
 |  |  |  |  |  |  |  |  | Max Ambient | 74.01380727
 |  |  |  |  |  |  |  |  | AuxSpecialFact | 1
 |  |  |  |  |  |  |  |  | Oly | 0

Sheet: Snapshot
 | Power Comparison Snapshots
Settings
Part
Ambient Temperature
Process
Implementation
Summary
Total On-Chip Power
Junction Temperature
Effective ΘJA
On-Chip Power
Clocking
Logic
I/O
BRAM
DSP
Transceiver
PS
Device Static
Supply Summary
VCCINT

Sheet: GTP
GTP Transceiver Power |  |  |  |  |  |  |  |  |  |  |  |  |  |  |  |  |  |  |  |  |  | FALSE | 1 | 3.75 |  |  |  |  |  |  |  | AI2:AI17
 |  |  |  |  |  |  |  |  |  |  |  |  |  |  |  |  |  |  |  |  |  |  |  |  |  |  |  |  |  |  | PCIe | 250 | 253
Active Current |  |  |  | Power |  |  |  |  | 0.587W |  | Utilization |  |  |  |  | Transceivers User Guide (http://www.xilinx.com/support/documentation/user_guides/ug482_7Series_GTP_Transceivers.pdf) |  |  |  |  |  |  |  |  |  |  |  |  |  |  |  | 300 | 316
Source |  | Active |  |  |  |  |  |  |  |  | GTP Channels |  | 4 | 100% |  |  |  |  |  |  |  |  |  |  |  |  |  |  |  |  |  | 350 | 377
VCCINT | 1.000V | 0.111A |  | Source | Power |  | PCIe | PCS | PMA |  |  |  |  |  |  | XPE Guide (http://www.xilinx.com/cgi-bin/docs/rdoc?l=en;v=latest;d=ug440-xilinx-power-estimator.pdf) |  |  |  |  |  |  |  |  |  |  |  |  |  |  |  | 400 | 439
MGTAVCC | 1.000V | 0.252A |  | VCCINT | 0.111W |  | 0.058W | 0.053W | 0.535W |  | Power Planes |  | 1 |  |  |  |  |  |  |  |  |  |  |  |  |  |  |  |  |  |  | 450 | 499
MGTAVTT | 1.200V | 0.235A |  | MGTAVCC | 0.252W |  |  |  |  |  |  |  |  |  |  | Introduction to XPE (video) (http://www.xilinx.com/training/vivado/using-the-xilinx-power-estimator.htm) |  |  |  |  |  |  |  |  |  |  |  |  |  |  |  | 500 | 561
 |  |  |  | MGTAVTT | 0.282W | 22% of total on-chip power 2.731W |  |  |  |  | BSCAN |  |  |  |  |  |  |  |  |  |  |  |  |  |  |  |  |  |  |  |  | 550 | 621
 |  |  |  |  |  |  |  |  |  |  |  |  |  |  |  |  |  |  |  |  |  |  |  |  |  |  |  |  |  |  |  | 600 | 682
 |  |  |  |  | RX |  |  | TX |  |  |  |  |  |  |  |  |  |  |  |  |  |  |  |  |  |  |  |  |  |  |  | 650 | 743
Name |  |  | GTP Channels | Operational Mode | Data Rate (Gb/s) | Data Path | Data Mode | Data Rate (Gb/s) | Data Path | Data Mode | O/P (mV) | OOB Used | Hard PCIe | VCCINT Power (W) | MGTAVCC Power (W) | MGTAVTT Power (W) |  | Operate Mode | Quads/PLLs | RX VCO Ring (MHz) | TX VCO Ring (MHz) | RX USERCLK | TX USERCLK | TX Voltage Swing Current | AVTT Current (ring) | AVCC Current (RX) | AVCC Current (TX) | AVCC Current (ring) | AVCC CLK | AVTT CLK | PCIe | 700 | 799
PCIe Gen2 |  |  | 4 | Transceiver | 3.0000 | 16 | 8b/10b | 3.0000 | 16 | 8b/10b | 909 | Yes | PCIe | 0.111 | 0.252 | 0.282 |  | 3 | 1 | 3000 | 3000 | 150 | 150 | 12 | 2.7 | 28.34 | 22 | 11.1 | 10 | 1.55 | 58 | 750 | 857
 |  |  |  | Transceiver | 3.1250 | 16 | 8b/10b | 3.1250 | 16 | 8b/10b | 253 |  |  | 0.000 | 0.000 | 0.000 |  | 3 | 0 | 3125 | 3125 | 156.25 | 156.25 | 3.75 | 2.8125 | 28.6875 | 22.375 | 11.5625 | 10 | 1.55 | 0 | 800 | 909
 |  |  |  | Transceiver | 3.1250 | 16 | 8b/10b | 3.1250 | 16 | 8b/10b | 253 |  |  | 0.000 | 0.000 | 0.000 |  | 3 | 0 | 3125 | 3125 | 156.25 | 156.25 | 3.75 | 2.8125 | 28.6875 | 22.375 | 11.5625 | 10 | 1.55 | 0 | 850 | 959
 |  |  |  | Transceiver | 3.1250 | 16 | 8b/10b | 3.1250 | 16 | 8b/10b | 253 |  |  | 0.000 | 0.000 | 0.000 |  | 3 | 0 | 3125 | 3125 | 156.25 | 156.25 | 3.75 | 2.8125 | 28.6875 | 22.375 | 11.5625 | 10 | 1.55 | 0 | 900 | 1002
 |  |  |  | Transceiver | 3.1250 | 16 | 8b/10b | 3.1250 | 16 | 8b/10b | 253 |  |  | 0.000 | 0.000 | 0.000 |  | 3 | 0 | 3125 | 3125 | 156.25 | 156.25 | 3.75 | 2.8125 | 28.6875 | 22.375 | 11.5625 | 10 | 1.55 | 0 | 950 | 1043
 |  |  |  | Transceiver | 3.1250 | 16 | 8b/10b | 3.1250 | 16 | 8b/10b | 253 |  |  | 0.000 | 0.000 | 0.000 |  | 3 | 0 | 3125 | 3125 | 156.25 | 156.25 | 3.75 | 2.8125 | 28.6875 | 22.375 | 11.5625 | 10 | 1.55 | 0 | 1000 | 1074
 |  |  |  | Transceiver | 3.1250 | 16 | 8b/10b | 3.1250 | 16 | 8b/10b | 253 |  |  | 0.000 | 0.000 | 0.000 |  | 3 | 0 | 3125 | 3125 | 156.25 | 156.25 | 3.75 | 2.8125 | 28.6875 | 22.375 | 11.5625 | 10 | 1.55 | 0
 |  |  |  | Transceiver | 3.1250 | 16 | 8b/10b | 3.1250 | 16 | 8b/10b | 253 |  |  | 0.000 | 0.000 | 0.000 |  | 3 | 0 | 3125 | 3125 | 156.25 | 156.25 | 3.75 | 2.8125 | 28.6875 | 22.375 | 11.5625 | 10 | 1.55 | 0
 |  |  |  | Transceiver | 3.1250 | 16 | 8b/10b | 3.1250 | 16 | 8b/10b | 253 |  |  | 0.000 | 0.000 | 0.000 |  | 3 | 0 | 3125 | 3125 | 156.25 | 156.25 | 3.75 | 2.8125 | 28.6875 | 22.375 | 11.5625 | 10 | 1.55 | 0
 |  |  |  | Transceiver | 3.1250 | 16 | 8b/10b | 3.1250 | 16 | 8b/10b | 253 |  |  | 0.000 | 0.000 | 0.000 |  | 3 | 0 | 3125 | 3125 | 156.25 | 156.25 | 3.75 | 2.8125 | 28.6875 | 22.375 | 11.5625 | 10 | 1.55 | 0
 |  |  |  | Transceiver | 3.1250 | 16 | 8b/10b | 3.1250 | 16 | 8b/10b | 253 |  |  | 0.000 | 0.000 | 0.000 |  | 3 | 0 | 3125 | 3125 | 156.25 | 156.25 | 3.75 | 2.8125 | 28.6875 | 22.375 | 11.5625 | 10 | 1.55 | 0
 |  |  |  | Transceiver | 3.1250 | 16 | 8b/10b | 3.1250 | 16 | 8b/10b | 253 |  |  | 0.000 | 0.000 | 0.000 |  | 3 | 0 | 3125 | 3125 | 156.25 | 156.25 | 3.75 | 2.8125 | 28.6875 | 22.375 | 11.5625 | 10 | 1.55 | 0
 |  |  |  | Transceiver | 3.1250 | 16 | 8b/10b | 3.1250 | 16 | 8b/10b | 253 |  |  | 0.000 | 0.000 | 0.000 |  | 3 | 0 | 3125 | 3125 | 156.25 | 156.25 | 3.75 | 2.8125 | 28.6875 | 22.375 | 11.5625 | 10 | 1.55 | 0
 |  |  |  | Transceiver | 3.1250 | 16 | 8b/10b | 3.1250 | 16 | 8b/10b | 253 |  |  | 0.000 | 0.000 | 0.000 |  | 3 | 0 | 3125 | 3125 | 156.25 | 156.25 | 3.75 | 2.8125 | 28.6875 | 22.375 | 11.5625 | 10 | 1.55 | 0
 |  |  |  | Transceiver | 3.1250 | 16 | 8b/10b | 3.1250 | 16 | 8b/10b | 253 |  |  | 0.000 | 0.000 | 0.000 |  | 3 | 0 | 3125 | 3125 | 156.25 | 156.25 | 3.75 | 2.8125 | 28.6875 | 22.375 | 11.5625 | 10 | 1.55 | 0
 |  |  |  | Transceiver | 3.1250 | 16 | 8b/10b | 3.1250 | 16 | 8b/10b | 253 |  |  | 0.000 | 0.000 | 0.000 |  | 3 | 0 | 3125 | 3125 | 156.25 | 156.25 | 3.75 | 2.8125 | 28.6875 | 22.375 | 11.5625 | 10 | 1.55 | 0
 |  |  |  | Transceiver | 3.1250 | 16 | 8b/10b | 3.1250 | 16 | 8b/10b | 253 |  |  | 0.000 | 0.000 | 0.000 |  | 3 | 0 | 3125 | 3125 | 156.25 | 156.25 | 3.75 | 2.8125 | 28.6875 | 22.375 | 11.5625 | 10 | 1.55 | 0
 |  |  |  | Transceiver | 3.1250 | 16 | 8b/10b | 3.1250 | 16 | 8b/10b | 253 |  |  | 0.000 | 0.000 | 0.000 |  | 3 | 0 | 3125 | 3125 | 156.25 | 156.25 | 3.75 | 2.8125 | 28.6875 | 22.375 | 11.5625 | 10 | 1.55 | 0
 |  |  |  | Transceiver | 3.1250 | 16 | 8b/10b | 3.1250 | 16 | 8b/10b | 253 |  |  | 0.000 | 0.000 | 0.000 |  | 3 | 0 | 3125 | 3125 | 156.25 | 156.25 | 3.75 | 2.8125 | 28.6875 | 22.375 | 11.5625 | 10 | 1.55 | 0
 |  |  |  | Transceiver | 3.1250 | 16 | 8b/10b | 3.1250 | 16 | 8b/10b | 253 |  |  | 0.000 | 0.000 | 0.000 |  | 3 | 0 | 3125 | 3125 | 156.25 | 156.25 | 3.75 | 2.8125 | 28.6875 | 22.375 | 11.5625 | 10 | 1.55 | 0
 |  |  |  | Transceiver | 3.1250 | 16 | 8b/10b | 3.1250 | 16 | 8b/10b | 253 |  |  | 0.000 | 0.000 | 0.000 |  | 3 | 0 | 3125 | 3125 | 156.25 | 156.25 | 3.75 | 2.8125 | 28.6875 | 22.375 | 11.5625 | 10 | 1.55 | 0
 |  |  |  | Transceiver | 3.1250 | 16 | 8b/10b | 3.1250 | 16 | 8b/10b | 253 |  |  | 0.000 | 0.000 | 0.000 |  | 3 | 0 | 3125 | 3125 | 156.25 | 156.25 | 3.75 | 2.8125 | 28.6875 | 22.375 | 11.5625 | 10 | 1.55 | 0
 |  |  |  | Transceiver | 3.1250 | 16 | 8b/10b | 3.1250 | 16 | 8b/10b | 253 |  |  | 0.000 | 0.000 | 0.000 |  | 3 | 0 | 3125 | 3125 | 156.25 | 156.25 | 3.75 | 2.8125 | 28.6875 | 22.375 | 11.5625 | 10 | 1.55 | 0
 |  |  |  | Transceiver | 3.1250 | 16 | 8b/10b | 3.1250 | 16 | 8b/10b | 253 |  |  | 0.000 | 0.000 | 0.000 |  | 3 | 0 | 3125 | 3125 | 156.25 | 156.25 | 3.75 | 2.8125 | 28.6875 | 22.375 | 11.5625 | 10 | 1.55 | 0
 |  |  |  | Transceiver | 3.1250 | 16 | 8b/10b | 3.1250 | 16 | 8b/10b | 253 |  |  | 0.000 | 0.000 | 0.000 |  | 3 | 0 | 3125 | 3125 | 156.25 | 156.25 | 3.75 | 2.8125 | 28.6875 | 22.375 | 11.5625 | 10 | 1.55 | 0
 |  |  |  | Transceiver | 3.1250 | 16 | 8b/10b | 3.1250 | 16 | 8b/10b | 253 |  |  | 0.000 | 0.000 | 0.000 |  | 3 | 0 | 3125 | 3125 | 156.25 | 156.25 | 3.75 | 2.8125 | 28.6875 | 22.375 | 11.5625 | 10 | 1.55 | 0
 |  |  |  | Transceiver | 3.1250 | 16 | 8b/10b | 3.1250 | 16 | 8b/10b | 253 |  |  | 0.000 | 0.000 | 0.000 |  | 3 | 0 | 3125 | 3125 | 156.25 | 156.25 | 3.75 | 2.8125 | 28.6875 | 22.375 | 11.5625 | 10 | 1.55 | 0
 |  |  |  | Transceiver | 3.1250 | 16 | 8b/10b | 3.1250 | 16 | 8b/10b | 253 |  |  | 0.000 | 0.000 | 0.000 |  | 3 | 0 | 3125 | 3125 | 156.25 | 156.25 | 3.75 | 2.8125 | 28.6875 | 22.375 | 11.5625 | 10 | 1.55 | 0
 |  |  |  | Transceiver | 3.1250 | 16 | 8b/10b | 3.1250 | 16 | 8b/10b | 253 |  |  | 0.000 | 0.000 | 0.000 |  | 3 | 0 | 3125 | 3125 | 156.25 | 156.25 | 3.75 | 2.8125 | 28.6875 | 22.375 | 11.5625 | 10 | 1.55 | 0
 |  |  |  | Transceiver | 3.1250 | 16 | 8b/10b | 3.1250 | 16 | 8b/10b | 253 |  |  | 0.000 | 0.000 | 0.000 |  | 3 | 0 | 3125 | 3125 | 156.25 | 156.25 | 3.75 | 2.8125 | 28.6875 | 22.375 | 11.5625 | 10 | 1.55 | 0
 |  |  |  | Transceiver | 3.1250 | 16 | 8b/10b | 3.1250 | 16 | 8b/10b | 253 |  |  | 0.000 | 0.000 | 0.000 |  | 3 | 0 | 3125 | 3125 | 156.25 | 156.25 | 3.75 | 2.8125 | 28.6875 | 22.375 | 11.5625 | 10 | 1.55 | 0
 |  |  |  | Transceiver | 3.1250 | 16 | 8b/10b | 3.1250 | 16 | 8b/10b | 253 |  |  | 0.000 | 0.000 | 0.000 |  | 3 | 0 | 3125 | 3125 | 156.25 | 156.25 | 3.75 | 2.8125 | 28.6875 | 22.375 | 11.5625 | 10 | 1.55 | 0
 |  |  |  | Transceiver | 3.1250 | 16 | 8b/10b | 3.1250 | 16 | 8b/10b | 253 |  |  | 0.000 | 0.000 | 0.000 |  | 3 | 0 | 3125 | 3125 | 156.25 | 156.25 | 3.75 | 2.8125 | 28.6875 | 22.375 | 11.5625 | 10 | 1.55 | 0
 |  |  |  | Transceiver | 3.1250 | 16 | 8b/10b | 3.1250 | 16 | 8b/10b | 253 |  |  | 0.000 | 0.000 | 0.000 |  | 3 | 0 | 3125 | 3125 | 156.25 | 156.25 | 3.75 | 2.8125 | 28.6875 | 22.375 | 11.5625 | 10 | 1.55 | 0
 |  |  |  | Transceiver | 3.1250 | 16 | 8b/10b | 3.1250 | 16 | 8b/10b | 253 |  |  | 0.000 | 0.000 | 0.000 |  | 3 | 0 | 3125 | 3125 | 156.25 | 156.25 | 3.75 | 2.8125 | 28.6875 | 22.375 | 11.5625 | 10 | 1.55 | 0
 |  |  |  | Transceiver | 3.1250 | 16 | 8b/10b | 3.1250 | 16 | 8b/10b | 253 |  |  | 0.000 | 0.000 | 0.000 |  | 3 | 0 | 3125 | 3125 | 156.25 | 156.25 | 3.75 | 2.8125 | 28.6875 | 22.375 | 11.5625 | 10 | 1.55 | 0
 |  |  |  | Transceiver | 3.1250 | 16 | 8b/10b | 3.1250 | 16 | 8b/10b | 253 |  |  | 0.000 | 0.000 | 0.000 |  | 3 | 0 | 3125 | 3125 | 156.25 | 156.25 | 3.75 | 2.8125 | 28.6875 | 22.375 | 11.5625 | 10 | 1.55 | 0
 |  |  |  | Transceiver | 3.1250 | 16 | 8b/10b | 3.1250 | 16 | 8b/10b | 253 |  |  | 0.000 | 0.000 | 0.000 |  | 3 | 0 | 3125 | 3125 | 156.25 | 156.25 | 3.75 | 2.8125 | 28.6875 | 22.375 | 11.5625 | 10 | 1.55 | 0
 |  |  |  | Transceiver | 3.1250 | 16 | 8b/10b | 3.1250 | 16 | 8b/10b | 253 |  |  | 0.000 | 0.000 | 0.000 |  | 3 | 0 | 3125 | 3125 | 156.25 | 156.25 | 3.75 | 2.8125 | 28.6875 | 22.375 | 11.5625 | 10 | 1.55 | 0
39
 |  |  |  |  |  |  |  |  |  |  |  |  |  |  |  |  |  |  |  | VCO MIN |  |  |  | 1.6
 |  |  |  |  |  |  |  |  |  |  |  |  |  |  |  |  |  |  |  | VCO MAX |  |  |  | 3.3
 |  |  |  |  |  |  |  |  |  |  |  | 0
 |  |  |  |  |  |  |  |  |  |  |  | 1
 |  |  |  |  |  |  |  |  |  |  |  | 2
 |  |  |  |  |  |  |  |  |  |  |  | 3
 |  |  |  |  |  |  |  |  |  | Power Planes | 1 | 4
 |  |  |  |  |  |  |  |  |  | Used Quad | 1 | 5
 |  |  |  |  |  |  |  |  |  | Used Pl | 1 | 6
 |  |  |  |  |  |  |  |  |  | Avg Quad | 1 | N61:N62
 |  |  |  |  |  |  |  |  |  | Quads |  | 1 |  |  | x^4 | x^3 | x^2 | x | c
 |  |  |  |  |  |  |  |  |  | AVCCQ |  | 0.002012971074 |  |  | 7.55266329e-08 | 5.467265515e-06 | 0.0004180628965 | 0.02142175782 | 0.3702050912
 |  |  |  |  |  |  |  |  |  | AVTTQ |  | 0.002549180477 |  |  | 1.018212675e-08 | -1.672192001e-08 | 4.392168573e-06 | 0.0008287392698 | 2.499111411
 |  |  |  |  |  |  |  |  |  |  |  | 0.004562151551 | 0.005071987647
 |  |  |  |  |  |  |  |  |  | BSCAN_AVTT | 0
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

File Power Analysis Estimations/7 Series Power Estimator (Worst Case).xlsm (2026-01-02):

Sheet: Summary
 |  |  | Xilinx Power Estimator (XPE) - 2019.1.2 |  |  |  |  |  |  |  |  |  |  |  |  |  |  |  |  |  |  |  |  |  |  |  |  | 1 |  | Pkgs | 1 | CLKROW | CLKCOL | LUT | FF | BRAM | MMCM | PLL | DSP | GT | PCIE |  | 3.3 Pins | Pins | Banks | ThetaJA | ThetaJB
 |  | Spartan®-7, Artix®-7, Kintex®-7, Virtex®-7, Zynq®-7000 |  |  |  |  |  |  |  |  |  |  | Release: 14-Aug-2019 |  |  |  |  |  |  |  |  |  |  |  |  |  |  |  |  | FTG256 | 7 | 4 | 54 | 63400 | 126800 | 135 | 6 | 6 | 240 | 0 | 1 | 0 | 285 | 285 | 17 | 15.8 | 6.8
 |  |  |  |  |  |  |  |  |  |  |  |  |  |  |  |  |  |  |  |  |  |  |  |  |  |  |  |  |  | CSG324 | 1 | 1 |  | 38016 |  |  |  |  |  | 0
 |  |  |  |  |  |  |  |  |  |  |  |  |  |  |  |  |  |  |  |  |  |  |  |  |  |  |  |  |  | FGG484 |  | 1
Project |  |  |  |  |  |  |  |  |  |  |  |  |  |  |  |  |  |  |  |  |  |  |  |  |  |  |  |  |  | FGG676 |  |  |  |  |  |  |  |  |  | 4
Settings |  |  |  |  | Summary
Device |  |  |  |  | Total On-Chip Power |  |  | 3.368 W |  |  | 17.44165812% | Transceiver…… |  | 0.587W
Family | Artix-7 |  |  |  |  |  |  |  |  |  | 9.065044403% | I/O……………… |  | 0.305W
Device | XC7A100T |  |  |  | Junction Temperature |  |  | 38.0 °C |  |  | 70.17213866% | Core Dynamic.. |  | 2.364W
Package | FGG484 |  |  |  | Thermal Margin |  |  | 47.0°C | 12.1W |  | 3.321158812% | Device Static….. |  | 0.112W |  |  |  |  |  |  |  |  |  |  |  |  |  | 10 | 2.16 | 0.09
Speed Grade | -1 |  |  |  | Effective ΘJA |  |  | 3.8 °C/W |  | Power supplied to off-chip devices… |  |  |  | 0.000W |  |  |  |  |  |  |  |  |  |  |  |  |  | 25 | 2.17 | 0.09
Temp Grade | Commercial |  |  |  |  |  |  |  |  |  |  |  |  |  |  |  |  |  |  |  |  |  |  |  |  |  |  | 40 | 2.19 | 0.11
Process | Typical |  |  |  | On-Chip Power |  |  |  |  |  | Power Supply |  |  |  |  |  |  |  |  |  |  |  |  |  |  |  |  | 55 | 2.22 | 0.14
Voltage ID Used | No |  |  |  | Resource |  |  | Power |  |  | Source |  | Voltage | Total (A) | Static | Active |  |  |  |  |  |  |  |  |  |  |  | 70 | 2.27 | 0.20 |  |  |  |  |  | static | 0
Characterization | Production |  |  |  |  |  | (Jump to sheet) | (W) | (%) |  | VCCINT |  | 1.000 | 2.051 | 0.027 | 2.023 |  |  |  |  |  |  |  |  |  |  |  | 85 | 2.36 | 0.29 |  |  |  |  |  |  | 1
 |  |  |  |  | Core Dynamic |  |  | 0.403 | 11.95252612 |  | VCCBRAM |  | 1.000 | 0.039 | 0.003 | 0.035 |  |  |  |  |  |  |  |  |  |  |  | 100 | 2.51 | 0.43 |  |  |  |  |  |  | 1
Environment |  |  |  |  |  |  |  | 0.815 | 24.1914907 |  | VCCAUX |  | 1.800 | 0.298 | 0.019 | 0.279 |  |  |  |  |  |  |  |  |  |  |  |  |  |  |  |  |  |  |  |  | 1
Junction Temperature |  |  | 38.0 °C |  |  |  |  | 0.546 | 16.20333231 |  | VCCAUX_IO |  | 2.000 | 0.000 | 0.000 | 0.000 |  |  |  |  |  |  |  |  |  |  |  | 0.95 | 2.10 |  |  |  |  |  |  |  | 1
Ambient Temp | 25.0 °C |  |  |  |  |  |  | 0.140 | 4.171029043 |  | VCCO 3.3V |  | 3.300 | 0.000 | 0.000 | 0.000 |  |  |  |  |  |  |  |  |  |  |  | 0.975 | 2.14 |  |  |  |  |  |  | 0 | 1
Effective ΘJA |  |  | 3.8 °C/W |  |  |  |  | 0.080 | 2.385619303 |  | VCCO 2.5V |  | 2.500 | 0.000 | 0.000 | 0.000 |  |  |  |  |  |  |  |  |  |  |  | 1 | 2.18 |  |  |  |  |  |  | 0 | 1
Airflow | 250 LFM |  |  |  |  |  |  | 0.223 | 6.632616026 |  | VCCO 1.8V |  | 1.800 | 0.000 | 0.000 | 0.000 |  |  |  |  |  |  |  |  |  |  |  | 1.025 | 2.22 |  |  |  |  |  |  | 0 | 1
Heat Sink | None |  |  |  |  |  |  | 0.098 | 2.913625302 |  | VCCO 1.5V |  | 1.500 | 0.000 | 0.000 | 0.000 |  |  |  |  |  |  |  |  |  |  |  | 1.05 | 2.27 |  |  |  |  |  |  | 0 | 1
ΘSA | 0.0 °C/W |  |  |  |  |  |  | 0.058 | 1.721899865 |  | VCCO 1.35V |  | 1.350 | 0.123 | 0.004 | 0.119 |  |  |  |  |  |  |  |  |  |  |  |  |  |  |  |  |  |  |  | 0.004 | 1
Board Selection | Medium (10"x10") |  |  |  | I/O |  |  | 0.305 | 9.065044403 |  | VCCO 1.2V |  | 1.200 | 0.000 | 0.000 | 0.000 |  |  |  |  |  |  |  |  |  |  |  |  |  |  |  |  |  |  |  | 0 | 1
# of Board Layers | 12 to 15 |  |  |  | Transceiver |  |  | 0.587 | 17.44165812 |  | MGTVCCAUX |  | 1.800 | 0.000 | 0.000 | 0.000 |  |  |  |  |  |  |  |  |  |  |  |  |  |  |  |  |  |  |  |  | 1
ΘJB | 2.6 °C/W |  |  |  |  |  |  | 0.000 | 0 |  | MGTAVCC |  | 1.000 | 0.255 | 0.002 | 0.252 |  |  |  |  |  |  |  |  |  |  |  |  |  |  |  |  |  |  |  |  | 1
Board Temperature | 25.0 °C |  |  |  |  |  |  | 0.000 | 0 |  | MGTAVTT |  | 1.200 | 0.238 | 0.003 | 0.235 |  |  |  |  |  |  |  |  |  |  |  | Temp | 50 | 85 | 100 |  |  |  |  |  | 1
 |  |  |  |  |  |  |  | 0.000 | 0 |  | - |  | 1.800 | 0.000 | 0.000 | 0.000 |  |  |  |  |  |  |  |  |  |  |  | Typical (1.0V) | 2.21 | 2.36 | 2.510693898 |  |  |  |  | 0 | 1
Implementation |  |  |  |  | Device Static | 0.112 |  | 0.112 | 3.321158812 |  | - |  | 1.075 | 0.000 | 0.000 | 0.000 |  |  |  |  |  |  |  |  |  |  |  | Maximum (1.05V) | 2.44 | 2.86 | 3.188937044 |  |  |  |  | 0 | 1
Optimization | Default |  |  | 1 |  |  |  |  |  |  | - |  | 1.075 | 0.000 | 0.000 | 0.000 |  |  |  |  |  |  |  |  |  |  |  |  |  |  |  |  |  |  |  | 0 | 1
 |  |  |  |  |  |  |  |  |  |  | - |  | 1.500 | 0.000 | 0.000 | 0.000 |  |  |  |  |  |  |  |  |  |  |  |  |  |  |  |  |  |  |  |  | 1
Messages |  |  |  |  |  |  |  |  |  |  | - |  | 1.800 | 0.000 | 0.000 | 0.000 |  |  |  |  |  |  |  |  |  |  |  |  |  |  |  |  |  |  |  |  | 1
 |  |  |  |  |  |  |  |  |  |  | - |  | 1.800 | 0.000 | 0.000 | 0.000 |  |  |  |  |  |  |  |  |  |  |  |  |  |  |  |  |  |  |  |  | 1
 |  |  |  |  |  |  |  |  |  |  | VCCADC |  | 1.800 | 0.020 | 0.020 | 0.000 |  |  |  |  |  |  |  |  |  |  |  |  |  |  |  |  |  |  |  | 0.02 | 1
XILINX Power Advantage (check for updates) (http://www.xilinx.com/products/technology/power/index.htm) |  |  |  | File Support Request (WebCase) (https://www.xilinx.com/support.html) |  |  |  |  |  |  | Xilinx Power Estimator User Guide (http://www.xilinx.com/cgi-bin/docs/rdoc?l=en;v=latest;d=ug440-xilinx-power-estimator.pdf)
© Copyright 1994-2019 Xilinx, Inc. All Rights Reserved |  |  |  | Introduction to XPE (video) (http://www.xilinx.com/training/vivado/using-the-xilinx-power-estimator.htm) |  |  |  | Whitepaper - 7 Steps for Worst Case Power Estimation (http://www.xilinx.com/support/documentation/white_papers/wp353.pdf)
Legend |  | User Entry |  |  | Calculated Value |  | Summary Value |  |  | User Override |  | Warning |  | Error
 |  |  |  |  |  |  |  |  |  |  |  |  |  |  |  |  |  |  | JEDEC | 12.1
 |  |  |  |  | Piccq | Iccauxq | Tj | Iccq |  |  |  |  |  |  |  |  |  |  | BoardType | 2 |  | Airflow | Opt | Leakage | 0.112 | 27.40084893 | Utilization
 |  |  |  | 0.003450882537 | 0 | 0.01907334898 | 37.83122631 | 0.02746430701 | Non-int Leakage | 0.0343 |  |  |  |  |  |  |  |  | BoardLyr | 2 |  | N/A | Default | CLOCK | 0.402605592 | 3.450882537
 |  |  | Temp | 37.83122631 | 0 | 0.01906644843 | 37.76602476 | 0.0274011316 | Scaled ICCQ_D | 0.0169 |  |  |  | Max Adj | Typ Adj |  |  |  | Airflow | 1 |  | 0 | Power Optimization | LOGIC | 0.8148594985 | 19.06641757
 |  |  | Initial | 37.71899325 | 0 | 0.01906641771 | 37.76573393 | 0.02740085019 | Non-aux Leakage | 0.0336 |  |  | MMF Factor | 1 | 0.9 |  |  |  | Heatsink | 3 |  | 250 | Powered Off | BRAM | 0.545788575 | 0
 |  |  | Max | 125 | 0 | 0.01906641757 | 37.76573264 | 0.02740084893 | Scaled ICCAUXQ_D | 0.1086 |  |  | MMF Aux | 1 | 1.38 |  |  |  | Pkg size | 529 |  | 500 | Y44:Y45 | DSP | 0.1404957915 | 0
 |  |  |  |  | 0 | 0.01906641757 | 37.76573263 | 0.02740084893 | Iccint_c1 | 1.083667432e-05 |  |  | MMF Bram | 1 | 0.7 |  |  |  | Air | 315.0598614 |  | 750 |  | PLL | 0.08035654241 | 0
 |  |  |  |  | 0 | 0.01906641757 | 37.76573263 | 0.02740084893 | Iccint_c2 | 0.0034 |  |  | VID Factor | 1 |  |  |  |  | ThetaSA | 0.000 |  | X45:X48 |  | MMCM | 0.2234112083 | 0
 |  |  |  |  | 0 | 0.01906641757 | 37.76573263 | 0.02740084893 | Iccintq_d | 0.0165 |  |  | Bali Factor | 1 |  |  |  |  | ThetaCS | 0.100 |  |  |  | PHASER | 0.0981417508 | 0
 |  |  |  |  |  |  |  |  | Iccintq_des | 0.0188 |  |  | Vccint | 2.068090477e-06 | 1.083667432e-05 | 0.003371762837 | 0.3283375125 | 5.19520427 | ThetaJB | 6.800 |  |  |  | PCIE | 0.058 | 4
 |  |  |  |  |  |  |  |  | Iccaux_c1 | -1.578356583e-06 |  |  | Vccaux | 1.986522681e-07 | -1.578356583e-06 | 0.0006360548088 | -0.007539738889 | 12.87473391 | ThetaJA | 3.847 |  |  |  | IO | 0.3053444546 | 0
 |  |  |  |  |  |  |  |  | Iccaux_c2 | 0.0006 |  |  | Vccbram | 1.10180825e-07 | -1.360770486e-06 | -8.670494492e-06 | 0.01047253566 | 0.06813210322 | ThetaJX | 3.894 |  |  |  | GTP | 0.5875 | 0
 |  |  |  |  |  |  |  |  | Iccauxq_d | 0.0131 |  |  |  |  |  |  |  |  | eThetaJA | 3.847 |  |  |  |  | 0 | 2.229673124
 |  |  |  |  |  |  |  |  | Iccoq | 0.0040 |  |  |  |  |  |  |  |  | TJA-Top | 12.100 |  |  |  |  |  | 2.55670076
 |  |  |  |  |  |  |  |  | Iccbram_c1 | -1.360770486e-06 |  |  |  |  |  |  |  |  | TJ | 39.664 |  |  |  |  |  | 0
 |  |  |  |  |  |  |  |  | Iccbram_c2 | -8.670494492e-06 |  |  |  |  |  |  |  |  | eThetaJA | 4.353 |  |  |  |  |  | 0
 |  |  |  |  |  |  |  |  | Iccbramq | 0.0031 | 0.002331 | 3.246224189 |  |  |  |  |  |  | Power | 3.362 |  |  |  |  |  | 0
 |  |  |  |  |  |  |  |  | Process | 1.0000 |  |  |  |  |  |  |  |  | Power2 |  |  |  |  |  |  | 0
 |  |  |  |  |  |  |  |  | I-Grade | 0.3283 |  |  |  |  |  |  |  |  | Temp | 65.679 |  |  |  |  |  | 0
 |  |  |  |  |  |  |  |  | Q-Grade | 5.1952 |  |  |  |  |  |  |  |  | Temp | 39.636 |  |  |  |  |  | 0
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

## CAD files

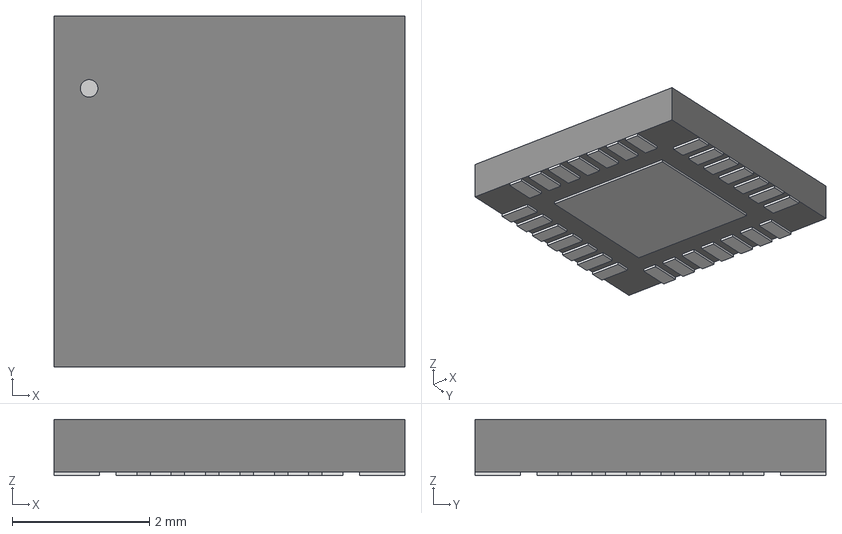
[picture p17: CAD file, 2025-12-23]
External Component Schematics/DC-DC Regulator - MAX20029ATIA_V_T/21-0140L_T2855-5_MXM.step
5.11 x 5.11 x 0.815 mm

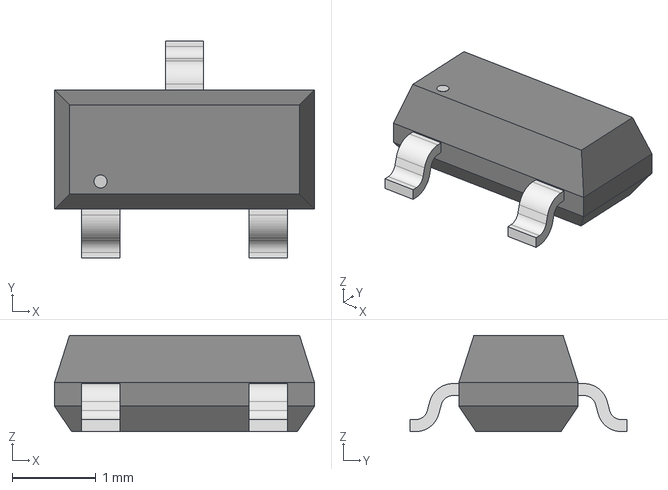
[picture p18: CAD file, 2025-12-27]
External Component Schematics/TVS Diode - GSOT04C_HE3_08/SOT_C-HE3-08_VIS.step
3.10 x 2.59 x 1.15 mm

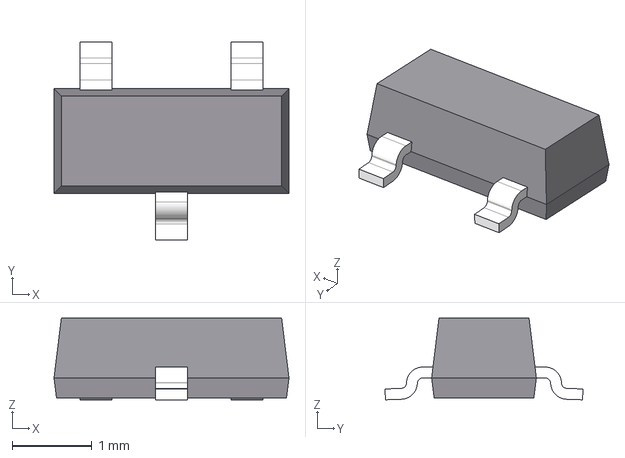
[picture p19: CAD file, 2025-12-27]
External Component Schematics/TVS Diode - GSOT04C_HE3_08/SOT-23_J.stp
2.95 x 2.48 x 1.02 mm

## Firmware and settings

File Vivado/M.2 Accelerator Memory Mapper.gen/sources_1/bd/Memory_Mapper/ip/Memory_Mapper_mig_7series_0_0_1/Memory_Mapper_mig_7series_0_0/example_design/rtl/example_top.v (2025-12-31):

//*****************************************************************************


// (c) Copyright 2023 Advanced Micro Devices, Inc. All rights reserved.


//


// This file contains confidential and proprietary information


// of AMD and is protected under U.S. and international copyright


// and other intellectual property laws.


//


// DISCLAIMER


// This disclaimer is not a license and does not grant any


// rights to the materials distributed herewith. Except as


// otherwise provided in a valid license issued to you by


// AMD, and to the maximum extent permitted by applicable


// law: (1) THESE MATERIALS ARE MADE AVAILABLE "AS IS" AND


// WITH ALL FAULTS, AND AMD HEREBY DISCLAIMS ALL WARRANTIES


// AND CONDITIONS, EXPRESS, IMPLIED, OR STATUTORY, INCLUDING


// BUT NOT LIMITED TO WARRANTIES OF MERCHANTABILITY, NON-


// INFRINGEMENT, OR FITNESS FOR ANY PARTICULAR PURPOSE; and


// (2) AMD shall not be liable (whether in contract or tort,


// including negligence, or under any other theory of


// liability) for any loss or damage of any kind or nature


// related to, arising under or in connection with these


// materials, including for any direct, or any indirect,


// special, incidental, or consequential loss or damage


// (including loss of data, profits, goodwill, or any type of


// loss or damage suffered as a result of any action brought


// by a third party) even if such damage or loss was


// reasonably foreseeable or AMD had been advised of the


// possibility of the same.


//


// CRITICAL APPLICATIONS


// AMD products are not designed or intended to be fail-


// safe, or for use in any application requiring fail-safe


// performance, such as life-support or safety devices or


// systems, Class III medical devices, nuclear facilities,


// applications related to the deployment of airbags, or any


// other applications that could lead to death, personal


// injury, or severe property or environmental damage


// (individually and collectively, "Critical


// Applications"). Customer assumes the sole risk and


// liability of any use of AMD products in Critical


// Applications, subject only to applicable laws and


// regulations governing limitations on product liability.


//


// THIS COPYRIGHT NOTICE AND DISCLAIMER MUST BE RETAINED AS


// PART OF THIS FILE AT ALL TIMES.


//


//*****************************************************************************


//   ____  ____


//  /   /\/   /


// /___/  \  /    Vendor             : AMD


// \   \   \/     Version            : 4.2


//  \   \         Application        : MIG


//  /   /         Filename           : example_top.v


// /___/   /\     Date Last Modified : $Date: 2011/06/02 08:35:03 $


// \   \  /  \    Date Created       : Tue Sept 21 2010


//  \___\/\___\


//


// Device           : 7 Series


// Design Name      : DDR3 SDRAM


// Purpose          :


//   Top-level  module. This module serves as an example,


//   and allows the user to synthesize a self-contained design,


//   which they can be used to test their hardware.


//   In addition to the memory controller, the module instantiates:


//     1. Synthesizable testbench - used to model user's backend logic


//        and generate different traffic patterns


// Reference        :


// Revision History :


//*****************************************************************************





//`define SKIP_CALIB


`timescale 1ps/1ps





module example_top #


  (





   //***************************************************************************


   // Traffic Gen related parameters


   //***************************************************************************


   parameter BEGIN_ADDRESS         = 32'h00000000,


   parameter END_ADDRESS           = 32'h00ffffff,


   parameter PRBS_EADDR_MASK_POS   = 32'hff000000,


   parameter ENFORCE_RD_WR         = 0,


   parameter ENFORCE_RD_WR_CMD     = 8'h11,


   parameter ENFORCE_RD_WR_PATTERN = 3'b000,


   parameter C_EN_WRAP_TRANS       = 0,


   parameter C_AXI_NBURST_TEST     = 0,





   //***************************************************************************


   // The following parameters refer to width of various ports


   //***************************************************************************


   parameter CK_WIDTH              = 1,


                                     // # of CK/CK# outputs to memory.


   parameter nCS_PER_RANK          = 1,


                                     // # of unique CS outputs per rank for phy


   parameter CKE_WIDTH             = 1,


                                     // # of CKE outputs to memory.


   parameter DM_WIDTH              = 2,


                                     // # of DM (data mask)


   parameter ODT_WIDTH             = 1,


                                     // # of ODT outputs to memory.


   parameter BANK_WIDTH            = 3,


                                     // # of memory Bank Address bits.


   parameter COL_WIDTH             = 10,


                                     // # of memory Column Address bits.


   parameter CS_WIDTH              = 1,


                                     // # of unique CS outputs to memory.


   parameter DQ_WIDTH              = 16,


                                     // # of DQ (data)


   parameter DQS_WIDTH             = 2,


   parameter DQS_CNT_WIDTH         = 1,


                                     // = ceil(log2(DQS_WIDTH))


   parameter DRAM_WIDTH            = 8,


                                     // # of DQ per DQS


   parameter ECC                   = "OFF",


   parameter ECC_TEST              = "OFF",


   //parameter nBANK_MACHS           = 4,


   parameter nBANK_MACHS           = 4,


   parameter RANKS                 = 1,


                                     // # of Ranks.


   parameter ROW_WIDTH             = 15,


                                     // # of memory Row Address bits.


   parameter ADDR_WIDTH            = 29,


                                     // # = RANK_WIDTH + BANK_WIDTH


                                     //     + ROW_WIDTH + COL_WIDTH;


                                     // Chip Select is always tied to low for


                                     // single rank devices





   //***************************************************************************


   // The following parameters are mode register settings


   //***************************************************************************


   parameter BURST_MODE            = "8",


                                     // DDR3 SDRAM:


                                     // Burst Length (Mode Register 0).


                                     // # = "8", "4", "OTF".


                                     // DDR2 SDRAM:


                                     // Burst Length (Mode Register).


                                     // # = "8", "4".
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

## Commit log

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2025-12-22 Found all of the unavailable footprints for the FPGA and M.2 slot. Also created the schematic pages that I'll use to organize my project.
    [1_Overview.SchDoc, 2_PowerRails.SchDoc, 3_PowerDistribution.SchDoc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]
2025-12-22 Forgot to bring in my Bank schematics and Vivado project for MIG for the last commit.
    [M.2 Accelerator.PrjPcb]
2025-12-23 Realized that a single download from SnapEDA contained all of the banks for the FPGA. Added the banks to each schematic page, as well as the DC-DC converter from Analog Devices, and the DRAM from Mic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
    [1_Overview.SchDoc, 21-0140L_T2855-5_MXM.step, 2_PowerRails.SchDoc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]
2025-12-23 Added a RED error light to PG4. Decided again adding lights to the other PG pins because they would always be on since they're also connected to the EN of cascading channels.
    [2_PowerRails.SchDoc]
2025-12-23 Made some more minor additions to the power rails, but then I realized I completely forgot about the resistor divider networks on the output for the adjustable output voltages.
    [2_PowerRails.SchDoc, 3_PowerDistribution.SchDoc]
2025-12-24 Redid the power rails schematic after taking notes from the DC-DC datasheet. Also added the feedback networks.
    [2_PowerRails.SchDoc, MAX20029ATIAV&plus_T - Modified.SchLib]
2025-12-24 Added my DC-DC IC notes. Also made a textbox for how I got the capacitor and resistor values like Phil suggested, and add my component annotations starting from 201 since this is Schematic/Page 2.
    [2_PowerRails.SchDoc]
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2025-12-24 Modified the schematic from SnapEDA to move around the power pins and organize everything better. Started working on the power distribution schematic.
    [2_PowerRails.SchDoc, 3_PowerDistribution.SchDoc, BGA484C100P22X22_2300X2300X260N.PcbLib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]
2025-12-25 Moved some of the power blocks to separate parts within the SnapEDA component. Finished the decoupling network for the Vccint, Vccbram, and Vccaux block.
    [3_PowerDistribution.SchDoc, 4_Configuration.SchDoc, 5_GPIOBanks.SchDoc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]
2025-12-25 Finished the rest of the power distribution. Still iffy on the 470 ohm ferrite beads on the MGTs since Phil used 120 and 470 might sink signals too much. Also need to circle back to banks 34 and 35 a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
    [3_PowerDistribution.SchDoc, 4_Configuration.SchDoc, 5_GPIOBanks.SchDoc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]
2025-12-25 Swapped the 470R ferrite bead on the MGT power rail for a 150R.
    [3_PowerDistribution.SchDoc]
2025-12-27 Chose a QSPI Flash IC from Micron and took some notes on it. Added it to my Config schematic and completed the wiring for it, now I'm trying to finish the wiring for Bank 0 and also get started on JT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
    [3_PowerDistribution.SchDoc, 4_Configuration.SchDoc, 5_GPIOBanks.SchDoc]
2025-12-27 Discovered the UG480 which contained the XADC description and layout.
    [3_PowerDistribution.SchDoc, 4_Configuration.SchDoc]
2025-12-27 Figured out the JTAG connection as well as what TVS diodes and what footprint to use for the plug-of-nails connector.
    [4_Configuration.SchDoc, GSOT04C-HE3-08.PcbLib, GSOT04C-HE3-08.SchLib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]
2025-12-27 Added some net classes to the JTAG and QSPI flash DQ lines.
    [4_Configuration.SchDoc]
2025-12-27 Finished the configuration mode pins. Hardwired them to QSPI flash.
    [4_Configuration.SchDoc]
2025-12-28 Added the 100 MHz oscillator and finished GPIO banks 13-16. Also decided to keep SMBus (optional) and figured out the PCIe sideband signals. Also added some images to the M.2 schematic page for futur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
    [2_PowerRails.SchDoc, 3_PowerDistribution.SchDoc, 4_Configuration.SchDoc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]
2025-12-28 Finished my notes on the Micron DDR3L and found the Arty A-7 schematic to source my decoupling cap values.
    [6_DRAMBanks.SchDoc, 7_DDR3L.SchDoc, 8_DDR3L.SchDoc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]
2025-12-29 Finally got a working memory configuration in Vivado.
    [3_PowerDistribution.SchDoc, 4_Configuration.SchDoc, 5_GPIOBanks.SchDoc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]
2025-12-29 Finished assigning the signals to banks 34-35 for the RAM.
    [6_DRAMBanks.SchDoc]
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2025-12-29 Readded the M.2 submodule and modified the B+M key schematic and linked it to the correct 3D PCB.
    [3_PowerDistribution.SchDoc, 8_PCIeBank.SchDoc, 9_M.2_B+M.SchDoc]
2025-12-29 Removed the M.2 footprint from timonsku to find some different options.
    [9_M.2_B+M.SchDoc]
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2025-12-29 Created a new integrated component file for the M.2 edge connector based on the schematic and footprint from Phil.
    [9_M.2_B+M.SchDoc, M2_2280_MKey.PcbLib, M2_2280_MKey.SchLib]
2025-12-30 Finished the M.2 M-key schematic. Not too sure about my decoupling for the 3V3 rail though.
    [2_PowerRails.SchDoc, 3_PowerDistribution.SchDoc, 5_GPIOBanks.SchDoc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]
2025-12-30 Added net colors to the power rails and spotted a couple issues.
    [2_PowerRails.SchDoc, 3_PowerDistribution.SchDoc, 4_Configuration.SchDoc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]
2025-12-31 Grabbed the Power Estimator spreadsheet from Xilinx and estimated about 2.18 W draw using the default logic deployment with DDR3L and a GTP being used.
    [7 Series Power Estimator.xlsm]
2025-12-31 Did some reconfiguring of the memory in the Vivado MIG and decided that it's better to have a 200 MHz LVDS clk because it can simplify some of our memory config.
    [2_PowerRails.SchDoc, 3_PowerDistribution.SchDoc, 4_Configuration.SchDoc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]
2025-12-31 Brought in Phil's components to use his net-ties for some of the labeling issues in the power regulator section. I'm not going to add net ties everywhere because I think they can be worse than traces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
    [2_PowerRails.SchDoc, 4_Configuration.SchDoc, 6_DRAMBanks.SchDoc]
2025-12-31 Finished labeling everything and started working on the Overview page. Also decided to move the 200 MHz clk to Page 6 for better organization.
    [1_Overview.SchDoc, 2_PowerRails.SchDoc, 3_PowerDistribution.SchDoc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]
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2026-01-01 Completely forgot to supply the VREFAC and VREFDQ pins for the DDR3.
    [2_PowerRails.SchDoc, 3_PowerDistribution.SchDoc, 4_Configuration.SchDoc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]
2026-01-01 Adjusted the power estimator to reflect the higher clock, and power did consumption did go up slightly, still below 3 Watts.
    [7 Series Power Estimator.xlsm]
2026-01-01 Finished added the net classes, now I need to add the net colors for the high speed signals.
    [7_DDR3L.SchDoc, 9_M.2_B+M.SchDoc]
2026-01-01 Added the net colors for the high speed signals, hopefully the colors don't make the PCB-view hard to look at.
    [5_GPIOBanks.SchDoc, 6_DRAMBanks.SchDoc, 7_DDR3L.SchDoc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]
2026-01-01 Played around with the Power Estimator and realized that my buck converter is inaccurately sized. Current draw on the 1V rail goes over 1.4 A for what I think might be a typical load. Phil's 35T was 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
    [2_PowerRails.SchDoc, 7 Series Power Estimator (Likely Case).xlsm, 7 Series Power Estimator (Worst Case) - Copy.xlsm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]
2026-01-02 Found a high current buck converter from Renesas. Took notes on the datasheet.
    [2_PowerRails.SchDoc, 7 Series Power Estimator (Worst Case) - Copy.xlsm]
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2026-01-02 Realized the PMIC for the XADC 1V25 rail was actually meant for 2V5 (Altium lied to me). Switched the 1V25 rail over to the quad channel buck.
    [2_PowerRails.SchDoc, M.2 Accelerator.PrjPcb]
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2026-01-02 Actually decided to move the power analysis docs to a folder for organization.
    [7 Series Power Estimator (Likely Case).xlsm, 7 Series Power Estimator (Worst Case) - Copy.xlsm]
